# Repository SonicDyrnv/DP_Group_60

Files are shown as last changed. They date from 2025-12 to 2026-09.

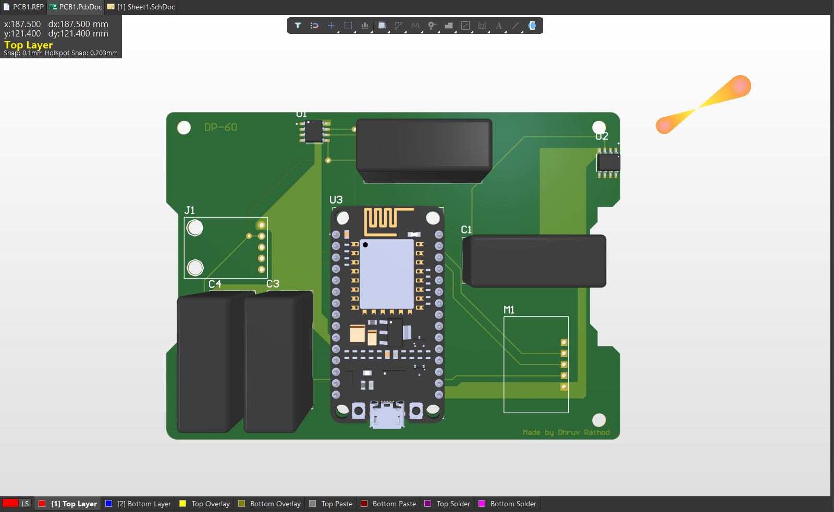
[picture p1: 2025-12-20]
Some_Overviews_In_Image/Screenshot 2025-12-20 130804.png

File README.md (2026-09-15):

# Streetlight Fault Detection & Ambulance Alerting System

An off-grid IoT system designed to monitor streetlight operations, detect physical and electrical failures in real time, and establish emergency acoustic corridors for ambulances using hybrid LoRa and ESP-NOW protocols.

---

## Overview

Traditional streetlight monitoring relies on internet connectivity or expensive cellular recharges. This project provides a cost-effective alternative that works without internet dependency. It identifies power, bulb, or structural failures at the pole level and integrates an ambulance path-clearing alert system managed from a central headquarters web portal.

---

## Key Features

* **Instant Structural Detection**: Detects pole tilting or falling immediately using 3-axis motion sensors.
* **Electrical & Light Fault Analysis**: Identifies tripped circuit breakers (MCBs), light failures when current is active, and LED flickering.
* **Ambulance Priority Corridor**: Allows HQ operators to send dynamic, targeted acoustic alerts to specific nodes to clear traffic along emergency routes.
* **Hybrid Connectivity**: Uses ESP-NOW for zero-latency node-to-node communication and long-range LoRa for transmission to the central server.

* **Continuous Power Backup**: Features an integrated battery management system recharged directly via streetlight power lines.

---

## Hardware Specifications

| Component | Function | Module Role |
| --- | --- | --- |
| **ESP32 Microcontroller** | Master controller handling LoRa & ESP-NOW stacks | Head Node |
| **ESP8266 Microcontroller** | Branch controller executing local sensing and peer routing | Branch Node |
| **LoRa SX1278 (433 MHz)** | Long-range low-power radio for HQ data link | Head Node |
| **ACS712 Current Sensor** | Measures real-time current draw to detect line flow | Both Nodes |
| **MPU6050 Gyro/Accel** | Monitors pole tilt, orientation changes, and falls | Both Nodes |
| **BH1750 Lux Sensor** | Measures digital light output intensity | Both Nodes |
| **HC-SR04 Ultrasonic** | Traffic and object distance monitoring | Both Nodes |
| **TP4056 Module** | Li-ion battery charging and protection circuit | Power System |

---

## Network Architecture

```text
               +-----------------------------+
               |  Central HQ Web Controller  |
               +--------------+--------------+
                              |
                       (LoRa 433 MHz)[cite: 1]
                              |
                              v
                   +------------------+
                   |    Head Node     | (ESP32)
                   +--------+---------+
                            |
                     (ESP-NOW Protocol)
                            |
           +----------------+----------------+
           v                                 v
+--------------------+             +--------------------+
|   Branch Node 1    | <--ESP-NOW->|   Branch Node 2    | (ESP8266)
+--------------------+             +--------------------+

```

---

## Working Principle

1. **Self-Diagnostic Loop**: Every 30 seconds, nodes read sensor inputs to evaluate power, illumination, and circuit status.
2. **Priority Interrupts**: Pole fall events bypass normal timer cycles and immediately trigger critical alarm frames.
3. **Emergency Routing**: HQ dispatches target messages formatted with `HeadNode_ID` and `BranchNode_ID`. If IDs match, local buzzers activate for a software-defined time interval.
4. **Data Relay**: Branch nodes hop messages via ESP-NOW until reaching the Head Node, which transmits packet logs to HQ over LoRa.

---

## Hardware Assembly & Manufacturing

* **Printed Circuit Board (PCB)**: Layout designed with isolated sensor tracks and centralized MCU placement to prevent signal attenuation.
* **Enclosure**: Built from 4mm laser-cut acrylic with a transparent top plate allowing unrestricted light intake for the BH1750 sensor.

---

## Authors

* **Team Members**: Rathod Dhruv Shailesh, Mayank Garg, Amey Shashikant Ballal, Avanish Kumar Patel, Divya Jain, Dilip Prajapat, Parth Vadhel.

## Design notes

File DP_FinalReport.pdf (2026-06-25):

Rathod Dhruv Shailesh∗, Mayank Garg⋆, Amey Shashikant Ballal◦ , Avanish Kumar Patel•, Divya Jain▷ , Dilip Prajapat◁ , Parth Vadhel⋄ ∗, ⋆, •, ⋄School of Computing and Electrical Engineering, Indian Institute of Technology, Mandi, India
- School of Mechanical and Material Engineering, Indian Institute of Technology, Mandi, India
▷ , ◁ School of Civil and Environmental Engineering, Indian Institute of Technology, Mandi, India
Email: yourgroupemail@students.iitmandi.ac.in

Keywords:
LoRa
ESP32
Radio receiver
Ambulance alerting system

A B S T R A C T

Streetlights are a very essential part of any road. Faults in these can lead to an increase in energy consumption and cause many accidents. For the minimization of such incidents, it is essential to fix these faulty streetlights at the fastest. The system proposed here is a solution for monitoring the functioning of a street light with addition of an alarming system for ambulances. The technology used behind this is LoRa, which is a wireless communication technology used for long range communication, ES32, a microcontroller used for short range communication (ESPNOW), wireless control and data collection and interfacing with different sensors like photo, current and orientation sensors to detect the faults. It is further embedded with an alarming system for clearance of traffic for ambulances which is done by installing an alarm and connecting with a radio receiver. Using web server programming, the data is displayed on a web page. This project was developed to produce a prototype product of a web-based streetlight fault detecting system that allows the user to detect the faulty street light. The enhancement from the existing systems is that this prototype system allowed the data to be monitored without the use of the internet and created a system for the alert for the clearance of the route for ambulances. This project involves two parts: hardware and software.

1 These authors contributed to the work equally.

## STREET LIGHT FAULT DETECTION

Streetlight Fault Detection

### 1. Introduction

Streetlight systems play an important role in ensuring public safety, energy efficiency, and comfort in urban environments. However, faults in streetlights often increase maintenance costs, lead to energy wastage, and cause illumination problems. This paper presents a streetlight fault detection and alerting system that utilizes current sensors, photosensors, ESP32 microcontrollers, and LoRa communication protocols for real-time fault reporting. The system also integrates an orientation sensor to detect the fallen streetlight poles, which is particularly useful in mountainous regions with sharp curves where continuous illumination is critical for public safety.
Beyond streetlight monitoring, this work also addresses the critical issue of ambulance delays due to traffic. The proposed design employs radio receivers integrated into selected streetlights, which are connected to an alarm system. We will have a website in our headquarters from which we will be able to monitor alarms of each streetlight with the help of LoRa Communications and ESPNOW communications. This mechanism assists in creating an emergency corridor, thereby reducing response times and improving emergency services.
The proposed solution is cost-effective, making it suitable for enhancing streetlight maintenance and energy management in urban environments.

1.Related works

Countries have millions of streetlights. It is important to detect faults in it, as it is put in work for the purpose of providing lighting in surroundings, so if they are not in working condition, they are not serving their basic purpose. Though there are various existing and proposed solutions based on IOTs, wifi based communications, GSM based communications, LoRa communications; many of them face high power consumptions, short ranges, monthly recharges and short period maintenance. Also, because we are implanting microcontrollers in most of those cases, there are large amounts of those that are underutilized, so there will also be a scope of future research on its utilizations.
- In [1] the authors used some sensors like light sensor, photo sensor, Ultrasonic sensor and LDR to detect the fault in the street light and give information about this to the center using GPS technology.
- In [2], [3] the authors used LoRaWAN (Long Range Wide Area Network) to develop a smart solution for detecting faults and automating the response over long distances with very low power consumption. Unlike in GSM and GPS systems, LoRa does not require any recharge with a working range of more than 10-15 km.
- In [4] authors suggest the idea to integrate LoRaWAN and ESPNOW communication technologies. They both work with limited energy but perform critical communication functions effectively. ESP-NOW enables short-range communication between ESP devices, whereas LoRAWAN provides longdistance transmission, The combination of these two technologies offers a cost effective and efficient solution for communication.
- In [5],[6] and [7], the authors propose a system that combines motion sensors and LDR (Light Dependent Resistor) sensors to control street lighting based on nearby movement and ambient light conditions. They also recommend an odd/even lighting scheme, where alternate lights are switched on, further optimizing energy consumption. This method helps to improve system efficiency, reduces energy usage and introduces the concept of an IoT-based dashboard for remote monitoring and management of street lights.
- In [8], 2 Author implemented system that uses traffic flow information worked on doppler effect to detect it and that system was implemented in Luyang Avenue, Lucheng City, Shanxi Province, China in May 2019, which reduced electricity consumption in that region by ∼18%.
- [9], [10], there is research on daily motionless activities of a human using Gyroscope, Accelerometer and magnetometer. The Gyroscope measures how fast an object rotates around the X, Y, Z axis. Accelerometer measures linear acceleration in the X, Y, Z axis. Magnetometer measures the direction of Earth’s magnetic field. Since these sensors detect change in orientation of the street light pole (eg. Check if the pole has fallen) and poles fall mostly in hilly areas and very few fall in urban areas so that sensor can be made attachable so that it can be deployed where it is required.
- In [11] the author proposed a smart ambulance system that computes an emergency route via Google maps APIs, the system then shares information with mobile users. The main base of this work was to inform all the other drivers on the same route as the ambulance, instead of depending on the vehicleto-vehicle or traffic management system. The author noted that if drivers do not keep his mobile app open then he would miss notification. Then the authors also suggested that future alerting systems should not rely completely on phone usage. This suggestion is important for our work, as it motivates us to use the microcontroller of our street light fault detection system for serving the purpose.
- In [12] the authors proposed an idea to solve the ambulance problem statement using the Zigbee module and when it came near the receiver then an alarm system turned ON to give information about the ambulance and it will work with the algorithm of master slave and master control.
2. Existing Products
- iSSL by ITHENA, INDIA
- Functionality: It uses NB-IOT based real-time fault alerts to improve energy efficiency, reduce maintenance costs and enhance overall light management. It includes adaptive brightness based on vehicular or human presence, and an automated schedule for turning the light on and off.
- Limitations: requires regular recharging, individual lamp monitoring is required, poor NB-IOT coverage in rural areas.
- Similarity with our solution: LoRa/LoRaWAN for long-range low-power communication, adaptive brightness system
- CityTouch Connect Cabinet Controller by Philips Signify
- Functionality: It monitors a group of streetlights. It measures voltage, current, power factor and energy consumption and detects the unauthorized opening of cabinet door. Uses web-based dashboard for real-time status and cellular network (like 2G, 3G and 4G).
- Limitations: it cannot identify the exact location of a fault within a group of streetlights, poor network availability in rural areas and the recurring cost of cellular network.
- Similarity with our solution: real-time status with the help of web-based dashboard, voltage and current monitoring
- CityLight by Motwane, India (Nashik, Maharashtra)
- Functionality: An integrated product that combines the streetlight with the dimmer. IoT-based automated, real-time monitoring and control of individual streetlights. Uses HPSV lights and adaptive brightness system to save power.
- Limitations: requires replacement of existing streetlights, it is dependent on continuous network connectivity, requires higher gateway cost.
- Similarity with our solution: adaptive brightness system, individual monitoring of lights, LoRa gateway to monitor/control light groups
- Waspmote Plug & Sense by Libelium (Spain)
- Functionality: This device can integrate multiple sensors, allowing it to be used for various tasks, one of which is smart streetlighting. It is a long range, low-power and retrofit-friendly device. It supports multiple communication protocols (LoRaWAN, Wi-Fi, Sigfox).
- Limitations: cannot identify fault at pole-level.
- Similarity with our product: Fault detection, adaptive brightness based on motion detection and scheduling of switching of light

- sylCloud by SYL Technologies sylCloud
- Functionality: It is a LoRa-based smart streetlight system. It uses map-based UI, dynamic dimming, and current/voltage monitoring. It can 6 detect overheating, voltage/current supply issues, power supply failures,
- Limitations: it requires continuous power and dense LoRa gateway placement in cities.
- Similarity with our solution: uses LoRa for communication, assigns a unique ID to each device for easy identification, and supports current, voltage, and light monitoring for fault detection
- CCMS by TRUEiSENSE (OCTIOT, India)
- Functionality: It is an IoT-based central control and monitoring system. It works on adaptive brightness based on motion detection, an automated alert system and control over individual streetlights.
- Limitations: it is dependent on network connectivity
- Similarity with our solution: Automated alerts and control over individual streetlights
- Smart Street Light Monitoring & Control by Neona Embedded Labz (India)
- Functionality: Cloud-based IoT system for managing and controlling groups of streetlights using company’s Data Connector Unit (DCU). The system uses scheduling to automatically turn lights on and off. It can store data for 45-60 days in case of network failure.
- Limitations: Scales well for highways, is dependent on network connectivity, does not provide real time information during network failures and involves higher maintenance complexity.
- Similarity with our solution: Streetlight fault Analysis
- inteliLIGHT by Flashnet / LORIOT (Europe) – Hafnarfjörður, Iceland
- Functionality: The product is based on adaptive LoRaWAN controllers with Central Management System (CMS), enabling real-time alerts. inteliLIGHT FRCM cabinet controllers and Zhaga-based controllers are used in it.
- Limitations: group-level control rather than per-lamp sensor granularity, requires reliable LoRaWAN coverage, and involves higher cost
- Similarity with our solution: it uses an AC–DC converter and operates in always-On Operation • SmartSky / Smartlight (LoRaWAN) by LOT
- EC (Turkey)
- Functionality: This system uses Light Control Unit (LCUs) are installed on each streetlight and communicate with the help of LoRaWAN controllers and DALI2(for sending data to MCU), it features a map-based interface for control, inbuilt GPS and App/web access.
- Limitations: Dependent on network connectivity and involves high costs
- Similarity with our solution: includes sensors, automated dimming, on/off scheduling of lights, and web-based monitoring
- ALC-P1 by Atreyo
- Functionality: This system uses long-range, radio-frequency-based devices (LoRa, etc.) for transmission of signals. It works on adaptive brightness system with automated on/off of streetlights and measures voltage, current and power. It supports Over the Air (OTA) for updating the fault detection logic.
- Limitations: We cannot get the pole level problem by this model
- Similarity with our solution: LoRa-based communication, adaptive brightness and current and voltage measurement

3.System Overview

The system is developed for the purpose of monitoring the streetlights and proving information regarding any fault in it. It is both hardware and software-based product.
- Objectives:
1. Identify tripping or falling of the Miniature Circuit Breaker (MCB) and generate an alert when the circuit is not completed
2. Detect tilting or falling of street light pole and generating an alert for maintenance or safety action
3. Detect the condition where current is flowing through the circuit but the LED is off
4. Detect abnormal flickering of street lights
5. Ambulance alerting system that communicate to assist emergency vehicle movements
6. Automatically dim/off street light when no motion is detected
- Advantages:
1. Real time fault detection for fast maintenance or safety action
2. Fast movement of emergency vehicles
3. No internet connection or wi-fi is required for communication
4. Continuous monitoring and fault detection in streetlight with their accurate location
5. No sim card is required, hence prevents the recharge cost
6. Much cheaper and more accurate compared to other models
7. Works even during the power cut with the help of battery
8. Charges the battery with the current in streetlight, hence the is no need to change battery

4.Hardware Used

1) ESP8266 Micro controller: Each branch node uses the ESP8266 microcontroller[14], which communicates with the ESP32 head node through ESP-NOW protocol or with other branch node through ESP-NOW protocol according to its positions. This low-latency, thus peers-topeers communication will reduce cost of external communication devices providing a local communication network. The ESP8266 collects sensor data, processes it and does as instructed. The main benefit of this is it has 11-usable GPIO pins which is enough for this system.
2) ESP32 Microcontroller: Each head node uses the ESP32 microcontroller[13], which communicates with the headquarters with the help of LoRa communications(head node). ESP32 has 30-usable GPIO pins allowing us to connect all sensors and Lora module. With its dual-core processor, integrated Wi-Fi, it is a good option since we require more pins.
3) ACS712 Current Sensor: The ACS712 5A Hall-effect current sensor[15] measures the real-time current consumption of connected loads or devices. Its high accuracy and galvanic isolation make it a good option for low-voltage IoT systems. In this system its high sensitivity is very useful.
4) MPU6050 Accelerometer and Gyroscope: The MPU6050 sensor[16] combines a 3-axis accelerometer and a 3-axis gyroscope to measure motion, tilt, and orientation. Data from this sensor allow the system to detect instant movements, enabling predictive maintenance or motion-based control applications. The sensor communicates with the microcontroller via I²C interface for efficient data transfer, which is useful for pole falling detection in this system.
5) BH1750 Light Intensity Sensor: The BH1750 sensor[17,18] is a digital light sensor that helps in detecting the amount of light intensity falling on the sensor in lux units. This sensor is useful in detecting the state of light (ON/OFF).

6) TP4056 Battery Backup System: The TP4056 module[21] is employed for charging and managing the lithium ion batteries used in the system. It provides overcharge, overdischarge, and short-circuit protection, ensuring safe and reliable operation of the power supply. The module takes care of battery charging, so there is no need of changing batteries.
7) 5V Relay Module: A 5V relay module[22] connected to the branch nodes to switch electrical loads based on sensor inputs or commands from the head node. The relay offers galvanic isolation between the low-voltage control circuitry and the high-voltage load. This device allows the microcontroller to do switching in circuits.
8) 220V AC Electronic Dimmer (E-Dimmer): The 220V ACE-Dimmer[23] allows to control the brightness of LEDs based on instructions received from the microcontroller. This helps reduce power consumption of street lights, especially in remote areas.
9) LoRa SX1278 433 MHz Transceiver Module: The LoRa SX1278 transceiver[19], operating at 433 MHz, facilitates long-range, low-power wireless communication between the head node and headquarters. Its low energy consumption and extended range make it ideal for distributed IoT networks that demand robust and scalable connectivity.
10) HC-SR04 Ultrasonic Sensor: The HC-SR04 sensor[20] is used for distance measurement, allowing us to measure change in distance for detecting motion and also distance itself, for measuring stable objects.

5.Design Overview
The proposed system uses ESP32 microcontroller in the headnode module, which contains Lora Communication module allowing it to communicate with farther devices and also supports ESP-NOW protocol allowing low-latency communications with branch nodes. Displayed Fig. 3 is the block diagram of the proposed system. A number of sensors are integrated by the branch nodes to monitor different physical properties. While the MPU6050 offers accelerometer and gyroscope data for motion and orientation detection, the ACS712 5A current sensor detects electrical current for the monitoring of electricity. The BH1750 sensor measures ambient light intensity, while the HC-SR04 ultrasonic sensor helps in measuring human traffic. A buzzer for alerts, a 5V relay module for electrical load switching or a servo motor for mechanical control and an electronic dimmer (E-Dimmer) for changeable brightness control are some of the devices used in actuation.
Two systems have been designed for different purposes
i. Head nodes
ii. Branch nodes

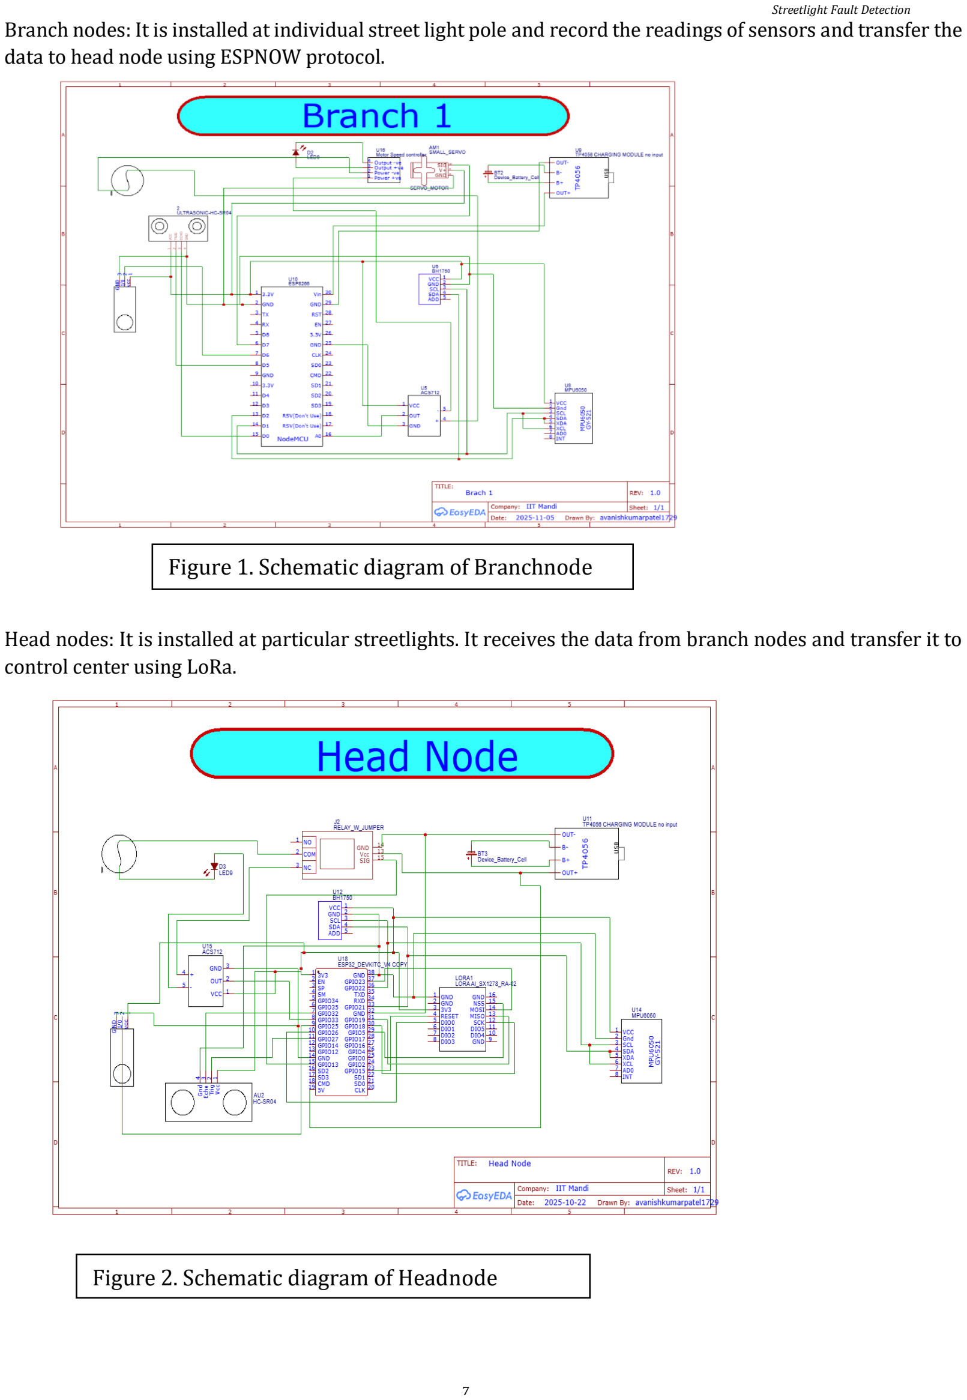
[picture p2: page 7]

Branch nodes: It is installed at individual street light pole and record the readings of sensors and transfer the data to head node using ESPNOW protocol.

Head nodes: It is installed at particular streetlights. It receives the data from branch nodes and transfer it to control center using LoRa.

Figure 1. Schematic diagram of Branchnode

Figure 2. Schematic diagram of Headnode

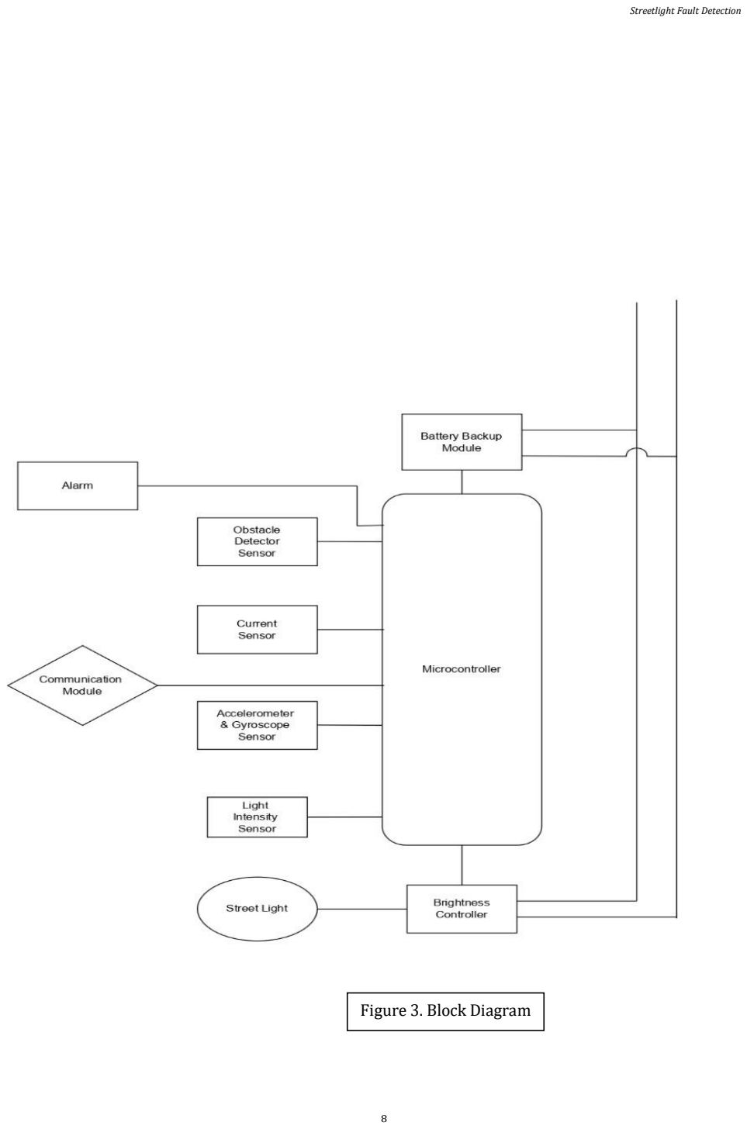
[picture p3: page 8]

Figure 3. Block Diagram

6.Working Principle

First branch node will start detecting and calibrating sensors, it will take readings of MPU6050 sensor, current sensor calibration, and detect weather all sensors including BH1750 is connected or not, if any of these is not connected it will generate fault message with all faults mentioned, the code has been written in a way such that it generates all such fault messages(some of faults are mentioned ahead) at duration of 30 seconds, till then it will just keep recording all readings and noticing all faults. The fault of fallen pole will be detected by change in readings of MPU6050, since it should be detected instantaneously as if the pole falls it can damage the system, so system should not wait for 30s if fault is of pole fallen, it should instantly generate message in this case, which is a feature of the code. Now it will detect if for some reason MCB has fallen and current is not going to LED light, then current sensor will not get detected by current sensor. Now if current is flowing but light has not turned on then in that case a photosensor will detect fault and generate a message but current sensor won’t since current is flowing. the feature of detection of flickering of LED light with the help of a photosensor has been added, through applying logic of continuous high and low readings of photosensor. Also in the case where current sensor is not detecting current and generating false faults messages, it has also been taken care in the code. All the system will be backed up by battery in case of power failure, till then it will work on adapter + cable power. The functionality mentioned above will be for both: Branchnode and Headnode. In case of Headnode(Fig. 5), the extra functionality of LoRa communication will be there, every branchnode will send fault message to Headnode by the help of espnow, and then later on Headnode will tranfer all these received fault messages to headquarter with the help of LoRa module installed in it, also it will have its own fault detecting system for own pole too. Now for clearing traffic for Ambulance, a mesh of network has been developed in which each head node has its own head node Id, if that head node id matches with the head node id transmitted then that head node will know that this alert message is either for its own or for its branchnodes. Now for reaching a particular targeted node, all head nodes will also have another id for particularly targeting it which will be in the same order with other branch nodes, those branch nodes will have its own branch node Ids only. Now whenever we transmit message of ALERT, first all head node will check if message Id of headnode in transmitted matches with its id or not, if it matches it will check if its branchnode id matches or not, if it doesn’t matches then it will transmit message to the 1st branchnode of that branch, that will check if id matches, if it will then ALERT message will successfully received by targeted node and buzzer will go on, if it doesn’t then it will transmit the same message to next node with the help of espnow, and this thing will continue until message die out, message will die out when it will reach to correct node. A feature of all node messaging is also developed, which will send a message alert to all nodes of a particular
headnode(including headnode since it will also have its own id+system). A feature of dynamic timing for buzzer being on has been added by which we will be able transmit the amount of time for buzzer to go on along with the message.

7.Manufacturing
1) PCB
The PCB of this system was designed considering the electrical requirements of all the electrical components. Schematic diagram was designed with correct pin mapping for all the electrical components. Adequate spacing between all the components has been given to reduce attenuation and interference. ESP has been placed centrally for easy connectivity with other components and photo sensor was placed near the enclosure to receive unrestricted light. Soldering has been done manually for prototype development. After assembly, the PCB was tested to endure the proper connectivity.

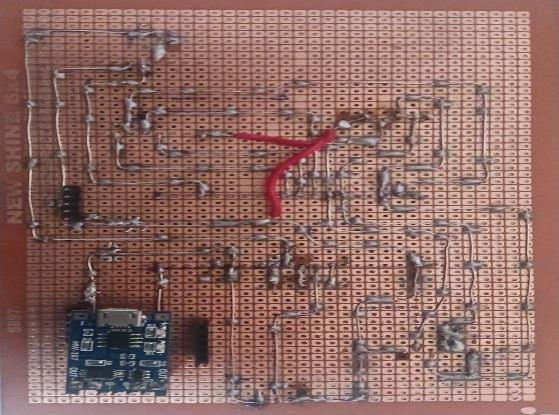
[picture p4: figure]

2) Boxing
The boxing of the streetlight fault detection unit was made up of 4 mm thick acrylic sheet as it offers good strength, electrical insulation, weather resistance and transparency for sensors that require optical exposure. This enclosure protects all the components from rai, dust and damage. The design of box was created in SolidWorks, the top face of the box is left transparent so that light fall directly over the photosensor so that it can detect the intensity of light without any resistance. The 2D profiles of each panel were exported as DXF filed and laser cutting of acrylic was done to ensure clean edges and accurate dimensions, these panels were then joint by L-brackets.
Finally, the PCB was mounted inside this box and were tested for the better functioning.

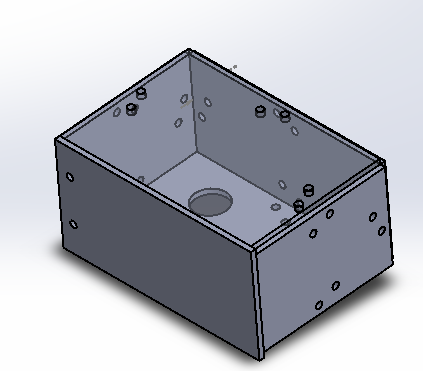
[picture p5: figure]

8.Testing

Figure 4. PCB design

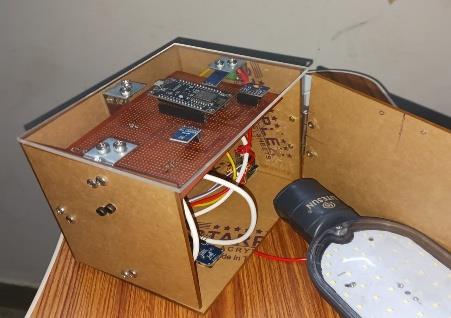
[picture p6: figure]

Figure 5. CAD design of enclosure | Figure 6. Street light fault detection system

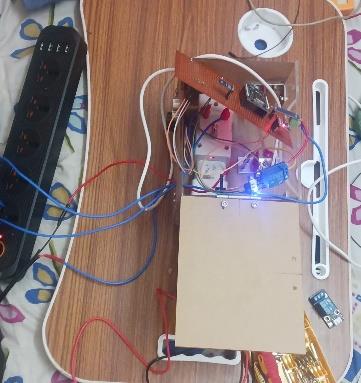
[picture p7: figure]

Figure 7. Assembling enclosure and PCB

The complete system underwent a structured testing process to ensure that it responded correctly to all fault scenarios.
1. When power supply was turned off, a “No current detected” warning was received along with the ID of that system.
2. When the system was moved, a “Pole fall detected” warning was generated along with system ID.
3. When power supply was turned on but the light was removed away from the system(condition of LED not working), “Low Light” fault was detected along with system ID.
4. When light was flickered over the system, “Flickering” fault was received along with system ID.
5. When the system received the message for ambulance, the buzzer started ringing. The operator can also manually decide the time for which buzzer has to ring.
Objectives 1, 2, 3, 4 and 5 were successfully achieved.
Objective 6 was not achieved, as the voltage was not enough to make adjustments in the intensity of light. We tried to achieve it by using servo+edimmer, relay module switchoff and ultrasonic sensor by was not able to control the intensity.

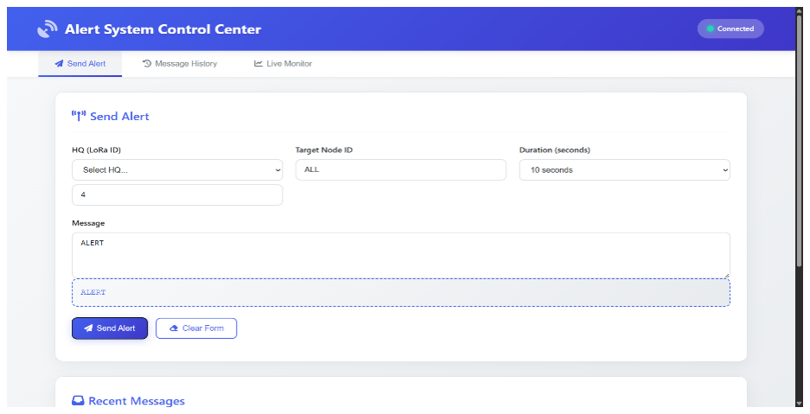
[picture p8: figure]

9.References

[1] Sathisha, K. G., Ashwinraj, Rahul, G. K., Sidharth, T., & Sneha, A. S. (2025, June). Centralized monitoring system for streetlight fault detection and location tracking. AIP Conference Proceedings, 3299(1), 050015.
[2] S. S. Saranya, C. K. P. Mani, and M. S. S. A. Tammana, “Integrat ing LoRa Technology for Smart Streetlight Systems: Enhancing Fault Detection and Adaptive Illumination,” in Proc. 2nd Int. Conf. Research Methodologies in Knowledge Management, Artificial Intelligence and Telecommunication Engineering (RMKMATE), 2025, pp. 20–25. doi: 10.1109/RMKMATE64874.2025.11042823.
[3] Bhuvaneswari, P.T.V., Parameswaran, R., Sabarna, S., Manogaran, G.I., Suriya, G., & Paventhan, A. (2020). LoRa Based Smart Street Light Management Framework. International Journal of Research in Electron ics and Computer Engineering, Vol. 6, Issue 3 (July–September 2018), ISSN: 2393-9028 (Print), ISSN: 2348-2281 (Online). Preprint available at ResearchGate.
[4] Selvaraj, V., Thamizhchelvan, A., Geca, M. J., & Natarajan, R. (2024). LoRaWAN and ESPNOW based hybrid communication system for monitoring applications. AIP Conference Proceedings, 2966(1), 020005.
[5] Aravind, S., Deepakumaran, S., Zubair, A. M., Selvam, M. E., Manish, M. P., & Venkatasamy, B. (2025). Intelligent street lighting system using RF communication. In Proceedings of the 8th International Conference on Trends in Electronics and Informatics (ICOEI) (pp. 104-109). IEEE.
[6] Hossain, A., Mostafa, S. M. G., Zilani, M. A. K., Talukder, O. I., Pranta, M. R., & Fahim, J. A. (2025). Design an Internet of Things (IoT) system for monitoring, fault detection, and controller development in street lighting. In 2025 International Conference on Electrical, Computer and Communication Engineering (ECCE). IEEE.
[7] Nanduri, A. K., Kotamraju, S. K., Sravanthi, G. L., Babu, S. R., & Kumar, K. V. K. V. L. P. (2020). IoT based automatic damaged street light fault detection management system. International Journal of Advanced Computer Science and Applications, 11(8), 412–415.

Figure 8. Manual Alert Control

[8] P. P. Ko, S. Y. Mon, and K. T. Mon, “Design and Construction of Smart Street Light System by Using Arduino and IR Sensor,” Kyaukse University Research Journal, vol. 3, pp. 143–150, 2024.
[9] Pires, I. M., Garcia, N. M., Zdravevski, E., & Lameski, P. (2022). Daily motionless activities: A dataset with accelerometer, magnetometer, gyroscope, environment, and GPS data. Scientific Data, 9, 105.
[10] Ciganda Brasca, L. M., Bernardi, P., Sonza Reorda, M., Barbieri, D., Bonaria, L., Losco, R., Marcigot, L., & Straiotto, M. (2011). A parallel tester architecture for accelerometer and gyroscope MEMS calibration and test. Journal of Electronic Testing, 27, 389–402.
[11] AbdelGhani Karkar,“Smart ambulance system for highlighting emergency-routes,” in Proc. 5th World Symposium on Web Applications and Networking (WS4), Marrakech, Morocco, 2019, pp. 1–7.
[12] Mr. G. Ramesh, Dr. V. Muneeswaran, Mr. P. Manikandan, Dr. T. Arun Prasath, “Detached range based Ambulance Alerting System,” in Proc. 2021 Int. Conf. on Advance Computing and Innovative Technologies in Engineering (ICACITE), IEEE, Gr. Noida, India, 2021, pp. 1–5, doi: 10.1109/ICACITE51222.2021.9404744.
[13] Espressif Systems, “ESP32 Series Datasheet v4.9”, Datasheet, Espressif Systems, Shanghai, China, Nov.2023.
[14] Espressif Systems, “ESP8266EX Datasheet”, Datasheet, Espressif Systems, Shanghai, China, Jul.2015.
[15] Allegro MicroSystems, “ACS712– Fully Integrated, Hall Effect-Based Linear Current Sensor”, Datasheet Rev. 7, Allegro MicroSystems, Worcester MA, USA, Sept. 2013.
[16] InvenSense Inc., “MPU-6000/MPU-6050 Motion Tracking Sensor”, Datasheet, InvenSense, San Jose CA, USA, 2013.
[17] NXP Semiconductors, “BH1750FVI Digital Light Sensor”, Datasheet, NXP, Eindhoven, The Netherlands, Apr. 2016.
[18] Sunrom Electronics, “Digital Light Sensor– BH1750FVI Module”, Module Spec, Sunrom Electronics, Chennai, India, 2024.
[19] Semtech Corporation, “SX1276/77/78/79 LoRa™ Long Range Transceiver”, Datasheet, Semtech Corporation, Camarillo CA, USA, 2017.
[20] ELECFREAKS, “HC-SR04 Ultrasonic Ranging Module,” Datasheet, Shenzhen, China, 2013.
[21] NanJing Top Power ASIC Corp., “TP4056– 1A Standalone Linear Li Ion Battery Charger,” Datasheet, Rev. 1.0, 2017.
[22] Songle Relay Co. Ltd., “SRD-05VDC-SL-C Relay Module,” Datasheet, Zhejiang, China, 2015.
[23] RobotDyn, “AC Light Dimmer Module for Arduino,” Module Specification, 2018

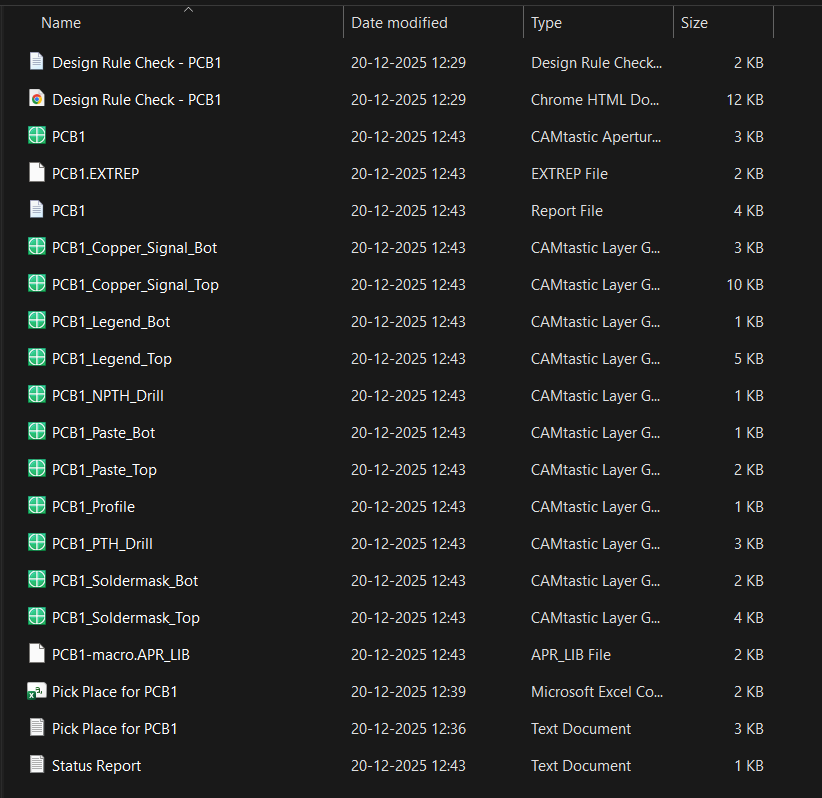
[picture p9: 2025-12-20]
Some_Overviews_In_Image/Screenshot 2025-12-20 130325.png

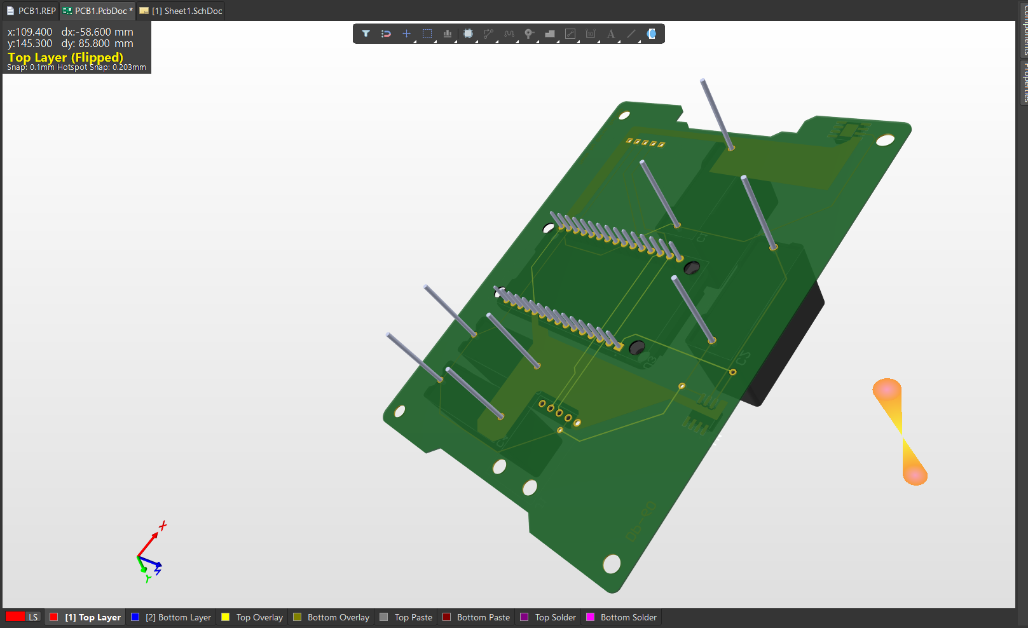
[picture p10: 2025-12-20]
Some_Overviews_In_Image/Screenshot 2025-12-20 130921.png

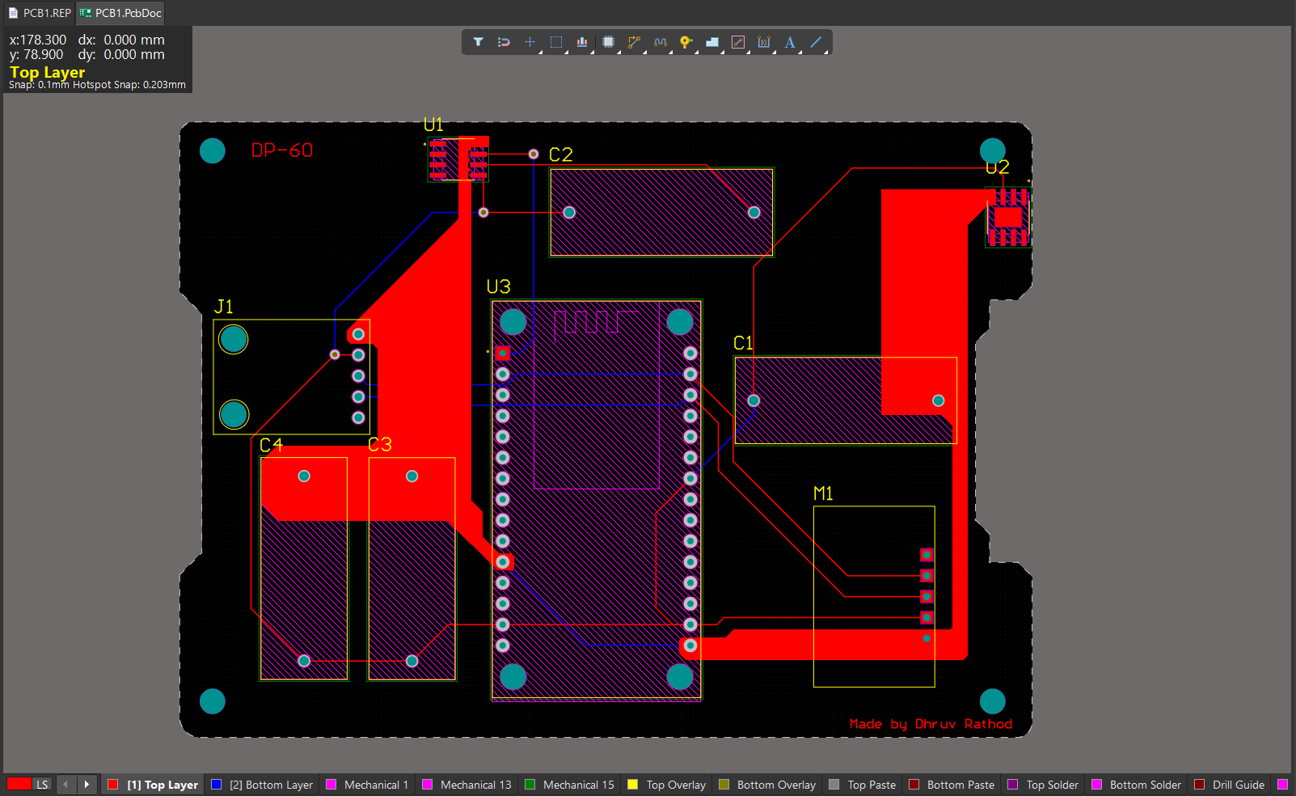
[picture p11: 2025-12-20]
Some_Overviews_In_Image/Screenshot 2025-12-20 130148.png

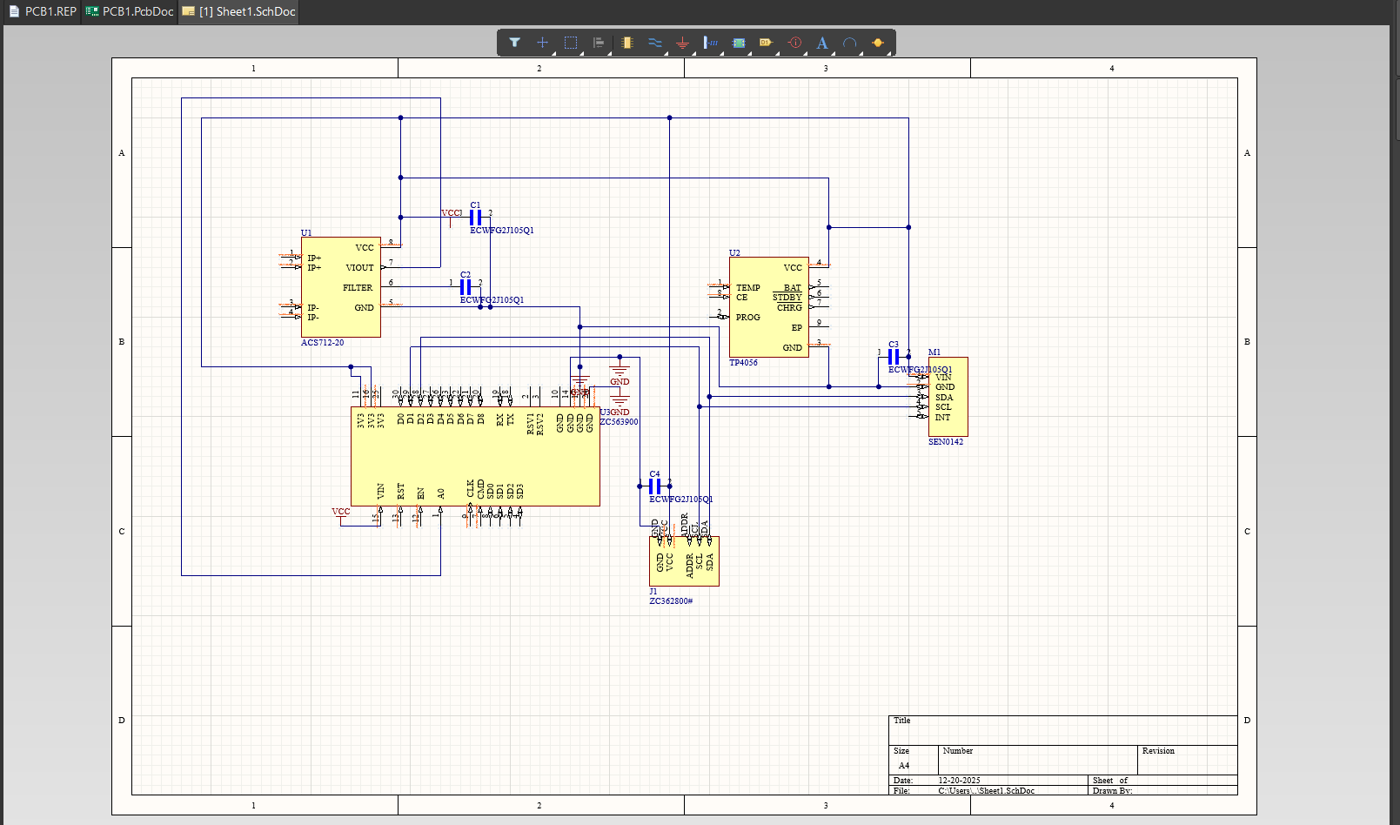
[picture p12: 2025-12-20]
Some_Overviews_In_Image/Screenshot 2025-12-20 130218.png

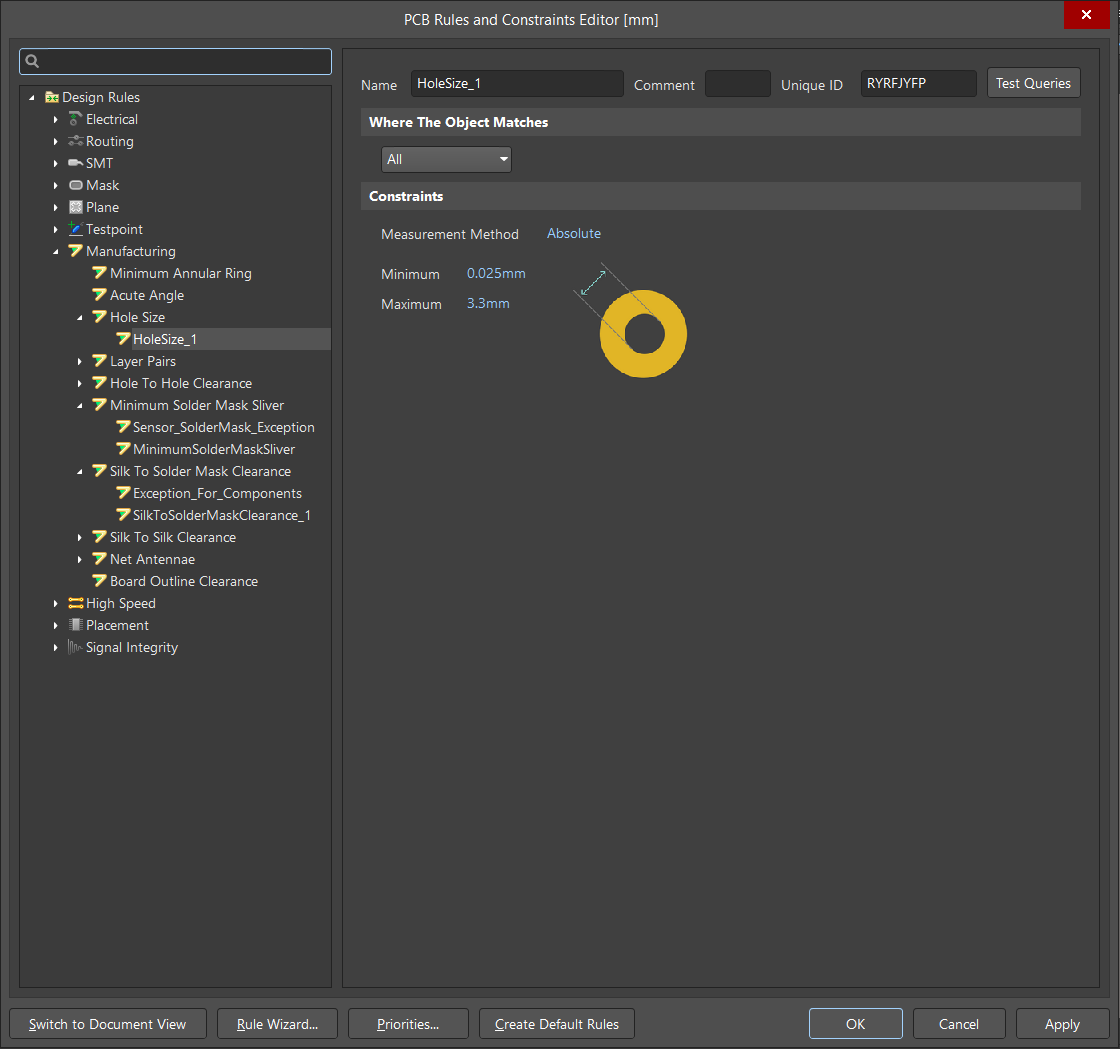
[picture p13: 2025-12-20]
Some_Overviews_In_Image/Screenshot 2025-12-20 130255.png

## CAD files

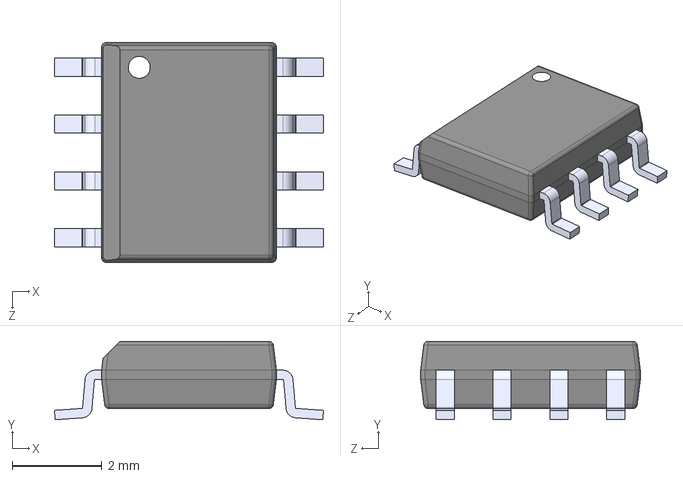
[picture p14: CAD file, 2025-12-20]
Comp_DP_60/ACS712-20.STEP
6.00 x 1.75 x 4.90 mm

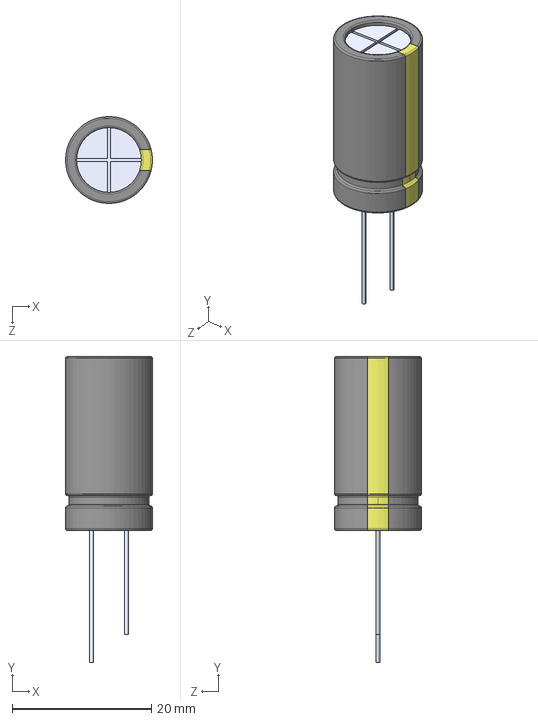
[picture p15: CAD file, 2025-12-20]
Comp_DP_60/478CKS010M--3DModel-STEP-1.STEP
12.5 x 44.0 x 12.5 mm

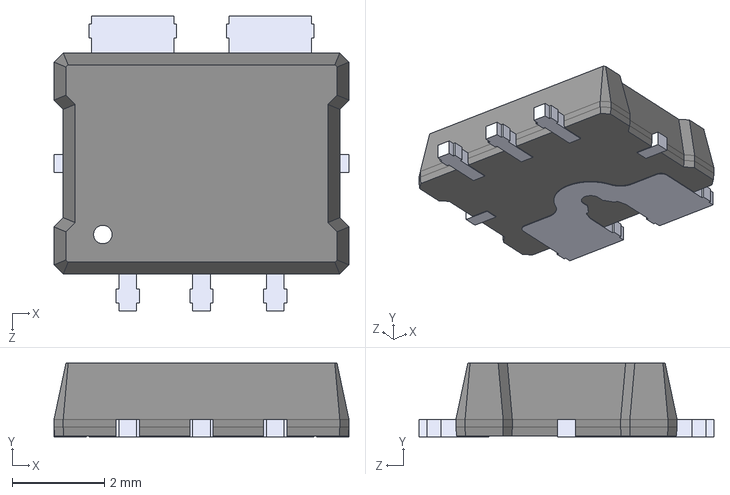
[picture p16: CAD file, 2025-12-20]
Comp_DP_60/ACS780LLRTR-100B-T.STEP
6.40 x 1.60 x 6.40 mm

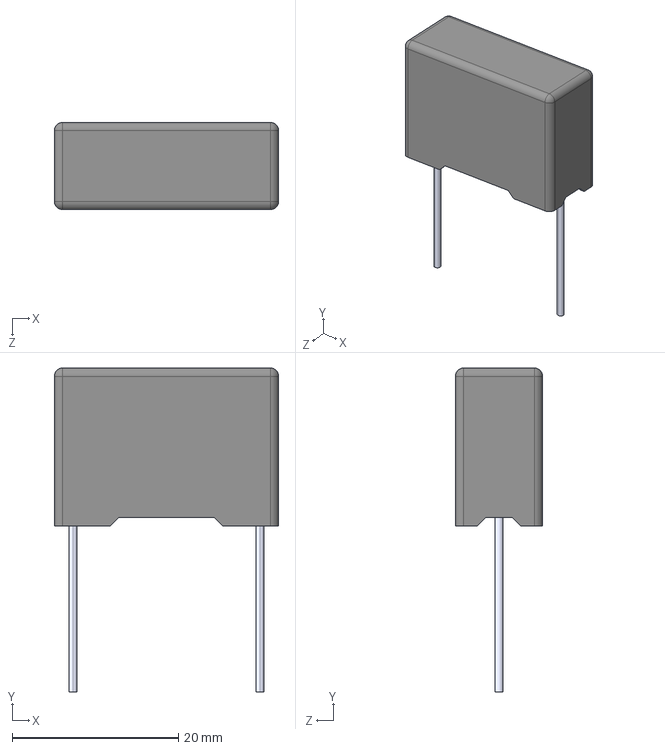
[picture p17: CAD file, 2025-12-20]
Comp_DP_60/ECWFG2J105Q1.STEP
27.0 x 39.0 x 10.5 mm

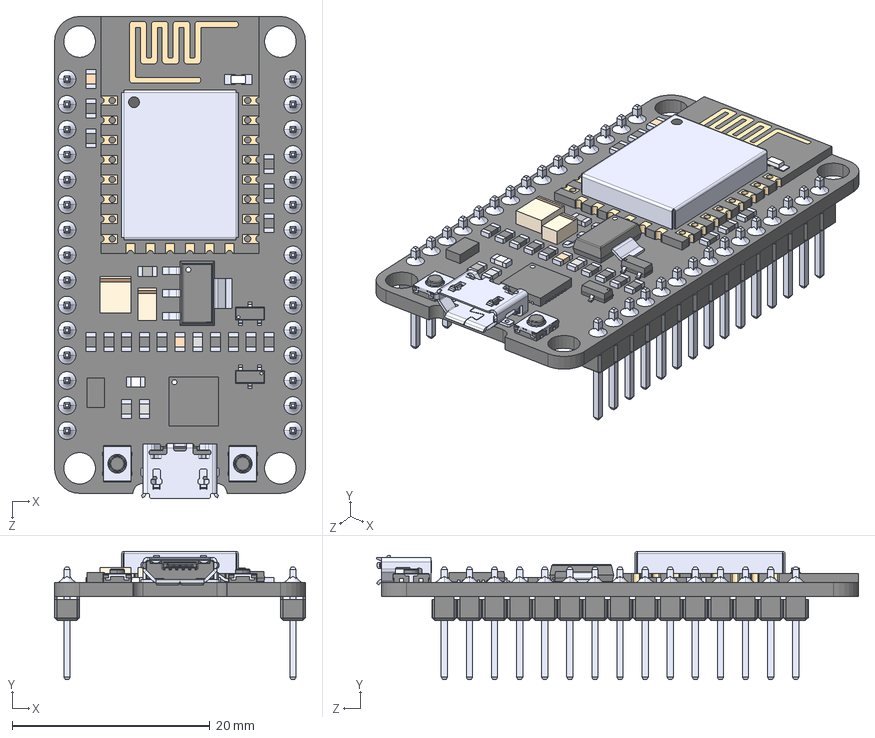
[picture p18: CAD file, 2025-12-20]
Comp_DP_60/ZC563900--3DModel-STEP-269445.STEP
25.4 x 13.0 x 48.8 mm

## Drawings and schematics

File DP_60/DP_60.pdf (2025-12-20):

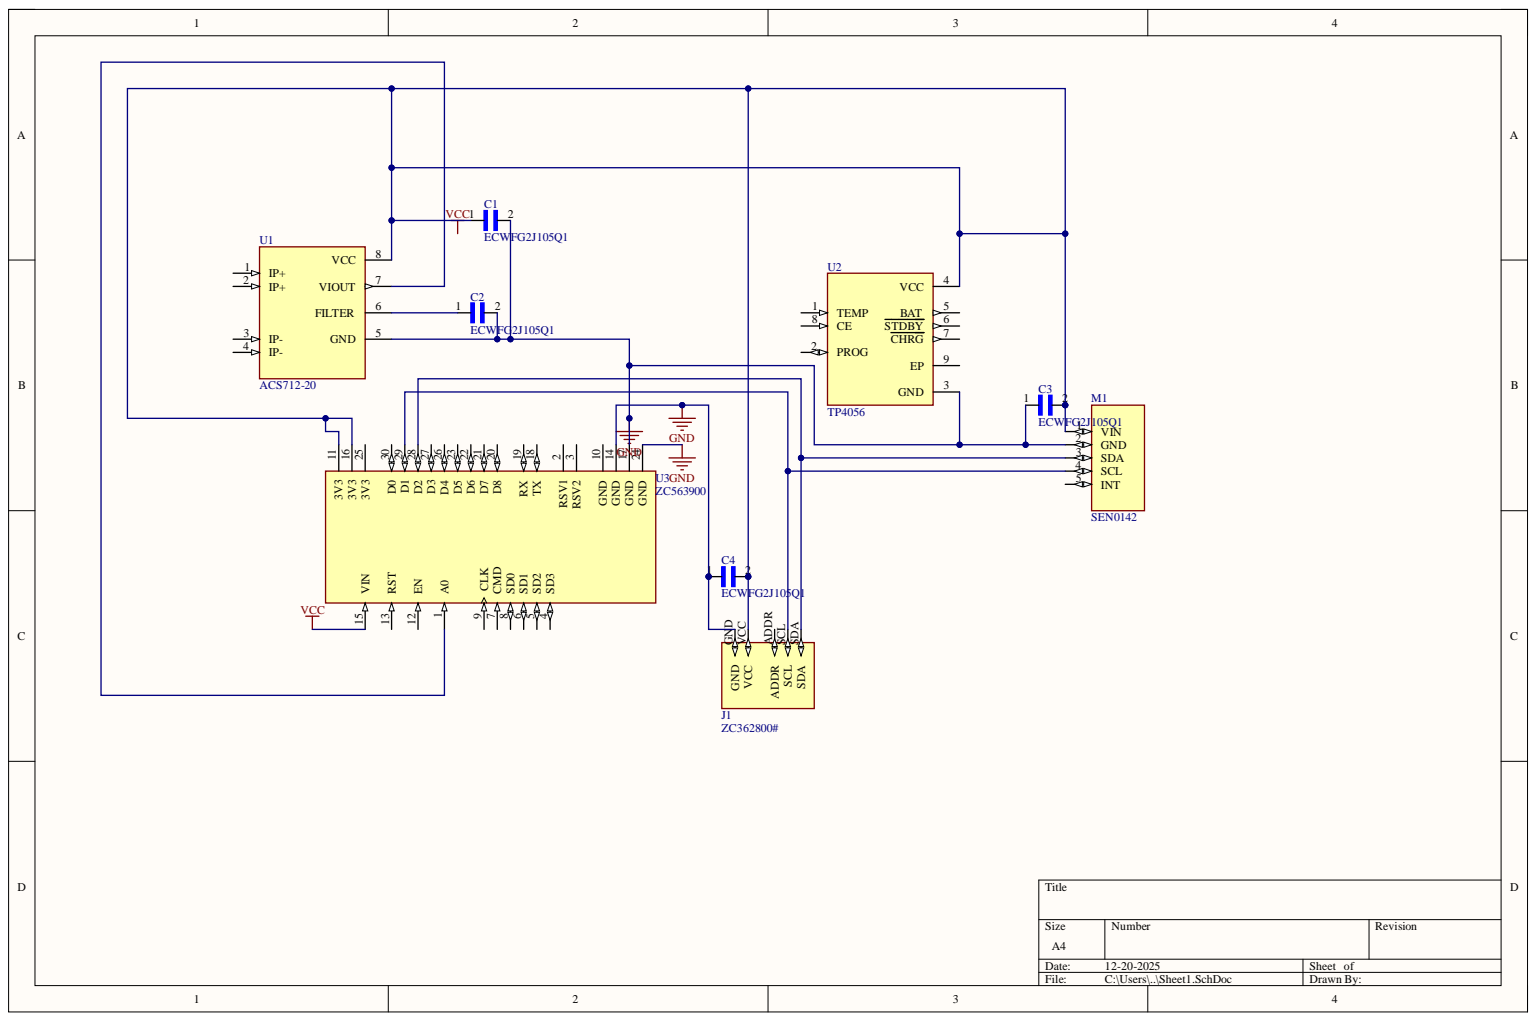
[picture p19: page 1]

SDA SDA SCL SCL ADDR ADDR

VCC VCC GND GND J1

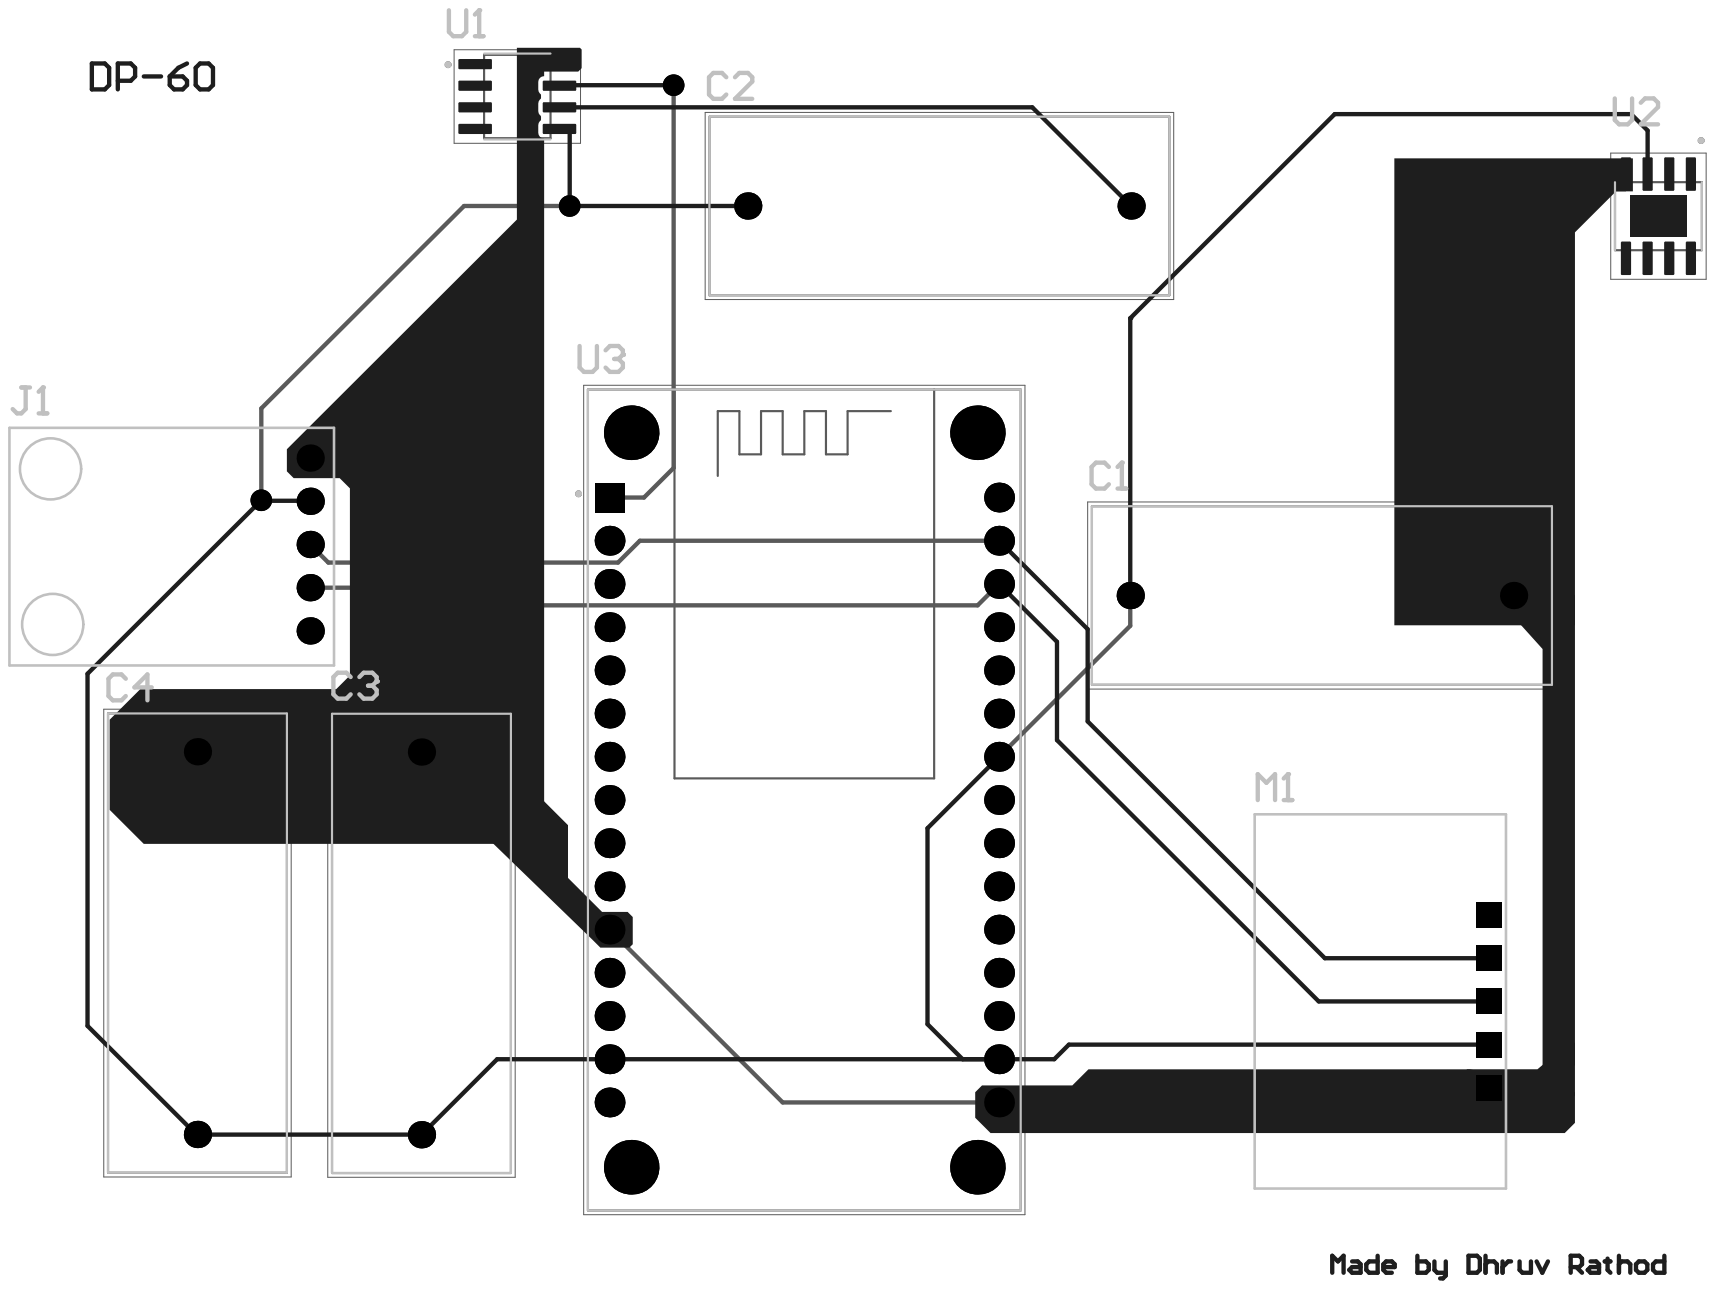
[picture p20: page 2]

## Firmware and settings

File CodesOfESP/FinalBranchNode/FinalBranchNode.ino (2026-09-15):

#include <ESP8266WiFi.h>
#include <espnow.h>
#include <Wire.h>
#include <BH1750.h>
#include <MPU6050.h>
#include <math.h>

// ---------------- CONFIG ----------------
#define NODE_ID "4001"     // change this for each branch node
#define BUZZER_PIN 12      // D6
#define ACS_PIN A0
#define LED_PIN 0          // D3
#define WIFI_CHANNEL 1

// ---------------- ESP-NOW PEERS ----------------
uint8_t prevNode[] = {0xF8,0xB3,0xB7,0x87,0x33,0xAA};  // Previous node MAC
uint8_t nextNode[] = {0x6C,0xC8,0x40,0x4F,0x69,0x94};  // Next node MAC

// ---------------- OBJECTS ----------------
BH1750 lightMeter;
MPU6050 mpu;

// ---------------- FLAGS ----------------
bool bh1750_ok = false;
bool mpu_ok = false;


// ---------------- THRESHOLDS / PARAMETERS ----------------
const float LUX_THRESHOLD = 300.0;
const unsigned long READ_INTERVAL = 1000;
const float TILT_THRESHOLD = 45.0;
const float CURRENT_THRESHOLD = 0.035;
const float alpha = 0.2;
const int SAMPLE_COUNT = 10;

// Pole fallen detection parameters - BALANCED SENSITIVITY
const float SPEED_CHANGE_THRESHOLD = 0.8;  // Sensitive but not too sensitive
const float ANGLE_CHANGE_THRESHOLD = 10.0; // Sensitive but not too sensitive
const unsigned long POLE_FALL_COOLDOWN = 30000;
const unsigned long POLE_FALL_CHECK_INTERVAL = 50; // Check every 50ms

// NEW: Direction-specific acceleration thresholds
const float X_ACCEL_THRESHOLD = 1.5;  // Threshold for X-axis acceleration (g)
const float Y_ACCEL_THRESHOLD = 1.5;  // Threshold for Y-axis acceleration (g)
const float Z_ACCEL_THRESHOLD = 2.0;  // Threshold for Z-axis acceleration (g)
const float ACCEL_DURATION_THRESHOLD = 100; // Minimum duration (ms) for acceleration to be considered

// Noise filtering
const float NOISE_THRESHOLD = 0.1; // Minimum change to consider
const int STABLE_READINGS = 2; // Need 2 stable readings before processing

// ---------------- GLOBAL VARS ----------------
float sensorOffset = 0.0;
float filteredCurrent = 0.0;
bool calibrated = false;
bool poleFallen = false;
float baselineX = 0.0, baselineY = 0.0, baselineZ = 1.0;

// For tracking changes in acceleration and angle
float prevAccelX = 0.0, prevAccelY = 0.0, prevAccelZ = 0.0;
float prevAngle = 0.0;
unsigned long lastPoleFallAlert = 0;
unsigned long lastPoleFallCheck = 0;
unsigned long lastMPUCheck = 0;
const unsigned long MPU_RECHECK_INTERVAL = 5000;

// NEW: Variables for direction-specific acceleration detection
unsigned long xAccelStartTime = 0;
unsigned long yAccelStartTime = 0;
unsigned long zAccelStartTime = 0;
bool xAccelDetected = false;
bool yAccelDetected = false;
bool zAccelDetected = false;

// Noise filtering variables
float stableAx = 0.0, stableAy = 0.0, stableAz = 0.0;
int stableCount = 0;

// Current sensor specific variables
unsigned long lastRecalibration = 0;
const unsigned long RECALIBRATION_INTERVAL = 11000;

// Fault generation cooldown
static unsigned long lastFaultGeneration = 0;
const unsigned long FAULT_GENERATION_COOLDOWN = 10000;

float luxSamples[SAMPLE_COUNT];
bool lightStates[SAMPLE_COUNT];
int sampleIndex = 0;
bool bufferFilled = false;

unsigned long lastCurrentRead = 0;
unsigned long lastSend = 0;

volatile bool msgPending = false;
String pendingMsg = "";
uint8_t pendingSender[6];

// ---------------- ALERT BUZZER VARIABLES ----------------
unsigned long alertStart = 0;
bool alertActive = false;
unsigned long alertDurationMs = 0;

// ---------------- FUNCTION DECLARATIONS ----------------
void sendTo(const uint8_t *mac, const String &msg);
void forwardMsg(const String &msg, const uint8_t *exclude);
void onDataRecv(uint8_t *mac, uint8_t *incomingData, uint8_t len);
void beep(int t);
float getSensorOffset();
float getACCurrent();
void calibrateMPU();
void checkSensors();
void triggerBuzzerFor(unsigned long ms);
void processIncomingMessage(const String &msg, const uint8_t *sender);
bool isSender(const uint8_t *mac1, const uint8_t *mac2);
void printMacAddress(const uint8_t *mac);
void recalibrateCurrentSensor();
void checkPoleFallAsync();
bool initializeMPU();
void sendPoleFallFault();

// ---------------- SETUP ----------------
void setup() {
  Serial.begin(9600);
  Serial.println("=== NODE " + String(NODE_ID) + " STARTING ===");

  pinMode(BUZZER_PIN, OUTPUT);
  pinMode(LED_PIN, OUTPUT);
  digitalWrite(BUZZER_PIN, LOW);
  digitalWrite(LED_PIN, LOW);

  Wire.begin(D2, D1);
  Wire.setClock(100000);

  // Initialize MPU6050 first
  mpu_ok = initializeMPU();
  
  // Sensors
  bh1750_ok = lightMeter.begin();
  if (bh1750_ok) Serial.println("BH1750 OK");
  else Serial.println("BH1750 not detected");

  // Calibrate current sensor - wait 60s for stabilization, then average 10 readings
  Serial.println("Calibrating current sensor... This will take approximately 70 seconds.");
  sensorOffset = getSensorOffset();
  Serial.print("Initial Sensor Offset: "); Serial.println(sensorOffset);
  lastRecalibration = millis();
  
  if (mpu_ok) calibrateMPU();

  // ESP-NOW setup
  WiFi.mode(WIFI_STA);
  WiFi.disconnect();

  if (esp_now_init() != 0) {
    Serial.println("ESP-NOW init failed!");
    ESP.restart();
  }

  esp_now_set_self_role(ESP_NOW_ROLE_COMBO);
  esp_now_register_recv_cb(onDataRecv);

  // Add peers with error checking
  if (esp_now_add_peer(prevNode, ESP_NOW_ROLE_COMBO, WIFI_CHANNEL, NULL, 0) != 0) {
    Serial.println("Failed to add previous node as peer");
  } else {
    Serial.print("Added previous node as peer: ");
    printMacAddress(prevNode);
  }
  
  if (esp_now_add_peer(nextNode, ESP_NOW_ROLE_COMBO, WIFI_CHANNEL, NULL, 0) != 0) {
    Serial.println("Failed to add next node as peer");
  } else {
    Serial.print("Added next node as peer: ");
    printMacAddress(nextNode);
  }

  Serial.println("System Ready, Node: " NODE_ID);
}

// ---------------- LOOP ----------------
void loop() {
  static unsigned long lastCheck = 0;

  if (msgPending) {
    processIncomingMessage(pendingMsg, pendingSender);
    msgPending = false;
  }

  if (alertActive && (millis() - alertStart >= alertDurationMs)) {
    digitalWrite(BUZZER_PIN, LOW);
    digitalWrite(LED_PIN, LOW);
    alertActive = false;
    Serial.println("Alert completed, buzzer off.");
  }

  if (millis() - lastCheck > 3000) {
    lastCheck = millis();
    checkSensors();
  }
  
  // Asynchronous pole fall detection - check every 50ms
  if (mpu_ok && calibrated) {
    checkPoleFallAsync();
  }
  
  // Periodically check MPU connection and try to reconnect if needed
  if (millis() - lastMPUCheck > MPU_RECHECK_INTERVAL) {
    lastMPUCheck = millis();
    if (!mpu_ok) {
      Serial.println("Attempting to reconnect MPU6050...");
      mpu_ok = initializeMPU();
      if (mpu_ok) {
        calibrateMPU();
        Serial.println("MPU6050 reconnected and recalibrated");
      }
    }
  }
  
  // Periodic recalibration to prevent drift
  if (millis() - lastRecalibration > RECALIBRATION_INTERVAL) {
    recalibrateCurrentSensor();
  }
}

// ---------------- MPU INITIALIZATION ----------------
bool initializeMPU() {
  for (int attempt = 0; attempt < 3; attempt++) {
    mpu.initialize();
    delay(100);
    
    if (mpu.testConnection()) {
      Serial.println("MPU6050 OK");
      mpu.setSleepEnabled(false);
      mpu.setFullScaleGyroRange(MPU6050_GYRO_FS_250);
      mpu.setFullScaleAccelRange(MPU6050_ACCEL_FS_2);
      return true;
    }
    delay(500);
  }
  
  Serial.println("MPU6050 not detected after 3 attempts");
  return false;
}

// ---------------- ASYNCHRONOUS POLE FALL DETECTION ----------------
void checkPoleFallAsync() {
  unsigned long now = millis();
  
  if (now - lastPoleFallCheck < POLE_FALL_CHECK_INTERVAL) {
    return;
  }
  lastPoleFallCheck = now;
  
  int16_t axRaw, ayRaw, azRaw;
  
  if (!mpu.testConnection()) {
    Serial.println("MPU6050 disconnected during pole fall check");
    mpu_ok = false;
    return;
  }
  
  mpu.getAcceleration(&axRaw, &ayRaw, &azRaw);
  float ax = axRaw / 16384.0;
  float ay = ayRaw / 16384.0;
  float az = azRaw / 16384.0;
  
  // Simple noise filtering - only process if change is significant
  float changeX = fabs(ax - stableAx);
  float changeY = fabs(ay - stableAy);
  float changeZ = fabs(az - stableAz);
  
  if (changeX < NOISE_THRESHOLD && changeY < NOISE_THRESHOLD && changeZ < NOISE_THRESHOLD) {
    stableCount++;
    if (stableCount >= STABLE_READINGS) {
      // Update stable values
      stableAx = ax;
      stableAy = ay;
      stableAz = az;
    }
  } else {
    // Significant change detected, reset stable count
    stableCount = 0;
  }
  
  // Use stable values for calculations
  float processAx = (stableCount >= STABLE_READINGS) ? stableAx : ax;
  float processAy = (stableCount >= STABLE_READINGS) ? stableAy : ay;
  float processAz = (stableCount >= STABLE_READINGS) ? stableAz : az;
  
  float totalG = sqrt(processAx * processAx + processAy * processAy + processAz * processAz);
  float currentAngle = 0;
  if (totalG > 0.0001) {
    currentAngle = acos(processAz / totalG) * (180.0 / PI);
  }
  
  float accelChange = sqrt(
    pow(processAx - prevAccelX, 2) + 
    pow(processAy - prevAccelY, 2) + 
    pow(processAz - prevAccelZ, 2)
  );
  
  float angleChange = fabs(currentAngle - prevAngle);
  
  // NEW: Check for direction-specific acceleration
  bool xAccelTriggered = false;
  bool yAccelTriggered = false;
  bool zAccelTriggered = false;
  
  // X-axis acceleration check
  if (fabs(processAx) > X_ACCEL_THRESHOLD) {
    if (!xAccelDetected) {
      xAccelDetected = true;
      xAccelStartTime = now;
    } else if (now - xAccelStartTime > ACCEL_DURATION_THRESHOLD) {
      xAccelTriggered = true;
    }
  } else {
    xAccelDetected = false;
  }
  
  // Y-axis acceleration check
  if (fabs(processAy) > Y_ACCEL_THRESHOLD) {
    if (!yAccelDetected) {
      yAccelDetected = true;
      yAccelStartTime = now;
    } else if (now - yAccelStartTime > ACCEL_DURATION_THRESHOLD) {
      yAccelTriggered = true;
    }
  } else {
    yAccelDetected = false;
  }
  
  // Z-axis acceleration check
  if (fabs(processAz - 1.0) > Z_ACCEL_THRESHOLD) {  // Subtract 1.0 to account for gravity
    if (!zAccelDetected) {
      zAccelDetected = true;
      zAccelStartTime = now;
    } else if (now - zAccelStartTime > ACCEL_DURATION_THRESHOLD) {
      zAccelTriggered = true;
    }
  } else {
    zAccelDetected = false;
  }
  
  // Debug output
  static unsigned long lastDebug = 0;
  // if (now - lastDebug > 200) {
  //   lastDebug = now;
  //   Serial.print("🔍 MPU - Accel: X=");
  //   Serial.print(processAx, 3);
  //   Serial.print(", Y=");
  //   Serial.print(processAy, 3);
  //   Serial.print(", Z=");
  //   Serial.print(processAz, 3);
  //   Serial.print(", Total=");
  //   Serial.print(totalG, 3);
  //   Serial.print(", Angle=");
  //   Serial.print(currentAngle, 2);
  //   Serial.print("°, AccelChange=");
  //   Serial.print(accelChange, 3);
  //   Serial.print(", AngleChange=");
  //   Serial.println(angleChange, 2);
  // }
  
  // Update previous values
  prevAccelX = processAx;
  prevAccelY = processAy;
  prevAccelZ = processAz;
  prevAngle = currentAngle;
  
  // Check cooldown
  if (now - lastPoleFallAlert < POLE_FALL_COOLDOWN) {
    return;
  }
  
  // IMMEDIATE DETECTION - Check any of the conditions
  bool poleFallDetected = false;
  String detectionReason = "";
  
  // Condition 1: Sudden acceleration change
  if (accelChange > SPEED_CHANGE_THRESHOLD) {
    poleFallDetected = true;
    detectionReason = "Acceleration change: " + String(accelChange, 3);
  }
  
  // Condition 2: Sudden angle change
  if (angleChange > ANGLE_CHANGE_THRESHOLD) {
    poleFallDetected = true;
    detectionReason = "Angle change: " + String(angleChange, 2) + "°";
  }
  
  // NEW: Condition 3: X-axis acceleration
  if (xAccelTriggered) {
    poleFallDetected = true;
    detectionReason = "X-axis acceleration: " + String(processAx, 3) + "g";
  }
  
  // NEW: Condition 4: Y-axis acceleration
  if (yAccelTriggered) {
    poleFallDetected = true;
    detectionReason = "Y-axis acceleration: " + String(processAy, 3) + "g";
  }
  
  // NEW: Condition 5: Z-axis acceleration
  if (zAccelTriggered) {
    poleFallDetected = true;
    detectionReason = "Z-axis acceleration: " + String(fabs(processAz - 1.0), 3) + "g";
  }
  
  // IMMEDIATE ACTION ON FIRST DETECTION
  if (poleFallDetected) {
    poleFallen = true;
    lastPoleFallAlert = now;
    
    Serial.println("POLE FALL DETECTED! Reason: " + detectionReason);
    Serial.println("Sending immediate fault...");
    
    sendPoleFallFault();
    // beep(5);
    
    // Reset flags after sending
    poleFallen = false;
    xAccelDetected = false;
    yAccelDetected = false;
    zAccelDetected = false;
  }
}

// ---------------- SEND POLE FALL FAULT ----------------
void sendPoleFallFault() {
  String msg = String(NODE_ID) + " -> FAULTS: [POLE_FALL]";
  Serial.println("Sending immediate pole fall fault: " + msg);
  forwardMsg(msg, NULL);
}

// ---------------- PROCESS INCOMING ----------------
void processIncomingMessage(const String &msg, const uint8_t *sender) {
  Serial.print("Received from ");
  printMacAddress(sender);
  Serial.println(": " + msg);

  String src = "", tgt = "", dur = "", cmd = "";
  bool isAlertFormat = false;
  
  if (msg.indexOf("SRC:") >= 0) {
    isAlertFormat = true;
    int pSrc = msg.indexOf("SRC:");
    int pTgt = msg.indexOf("|TGT:");
    int pDur = msg.indexOf("|DUR:");
    int pMsg = msg.indexOf("|MSG:");

    if (pSrc >= 0 && pTgt > pSrc) src = msg.substring(pSrc + 4, pTgt);
    if (pTgt >= 0 && pDur > pTgt) tgt = msg.substring(pTgt + 5, pDur);
    if (pDur >= 0 && pMsg > pDur) dur = msg.substring(pDur + 5, pMsg);
    if (pMsg >= 0) cmd = msg.substring(pMsg + 5);

    src.trim(); tgt.trim(); dur.trim(); cmd.trim();
    
    Serial.println("Parsed: SRC=" + src + ", TGT=" + tgt + ", DUR=" + dur + ", MSG=" + cmd);
  }

  if (isAlertFormat && (tgt == NODE_ID || tgt == "ALL")) {
    Serial.println("Target matches this node ID or ALL → Activating buzzer.");
    if (cmd.equalsIgnoreCase("ALERT")) {
      unsigned long durMs = dur.toInt() * 1000UL;
      if (durMs == 0) durMs = 5000;
      triggerBuzzerFor(durMs);
    }
  }
  else if (String(NODE_ID) == "4001" && isAlertFormat && cmd.equalsIgnoreCase("ALERT")) {
    Serial.println("ALERT not for 4001 → forwarding backward to previous node.");
    Serial.print("Forwarding to previous node: ");
    printMacAddress(prevNode);
    sendTo(prevNode, msg);
  }
  else {
    Serial.println("↩ Normal message flow → forward to both directions if applicable.");
    forwardMsg(msg, sender);
  }
  
  if (isAlertFormat && tgt == "ALL") {
    Serial.println("Forwarding ALL message to ensure it reaches all nodes");
    forwardMsg(msg, sender);
  }
}

// ---------------- TRIGGER BUZZER ----------------
void triggerBuzzerFor(unsigned long ms) {
  Serial.printf("Buzzing for %.1f sec...\n", ms / 1000.0);
  digitalWrite(BUZZER_PIN, HIGH);
  digitalWrite(LED_PIN, HIGH);
  alertStart = millis();
  alertDurationMs = ms;
  alertActive = true;
}

// ---------------- SENSOR CHECK ----------------
void checkSensors() {
  unsigned long now = millis();
  String faultList = "";

  float lux = -1, tiltAngle = -1;
  String lightStatus = "N/A";

  // BH1750
  if (bh1750_ok) {
    lux = lightMeter.readLightLevel();
    if (lux >= 0 && lux < 200000) {
      luxSamples[sampleIndex] = lux;
      lightStates[sampleIndex] = (lux >= LUX_THRESHOLD);
      sampleIndex = (sampleIndex + 1) % SAMPLE_COUNT;
      if (sampleIndex == 0) bufferFilled = true;

      int validCount = bufferFilled ? SAMPLE_COUNT : sampleIndex;
      int onCount = 0, offCount = 0, stateChanges = 0;
      for (int i = 0; i < validCount; i++) {
        if (lightStates[i]) onCount++;
        else offCount++;
        if (i > 0 && lightStates[i] != lightStates[i - 1]) stateChanges++;
      }

      if (stateChanges >= 3) lightStatus = "FLICKERING";
      else if (onCount == validCount) lightStatus = "ON";
      else if (offCount == validCount) lightStatus = "OFF";
      else lightStatus = "TRANSITION";
    } else {
      faultList += "LIGHT_SENSOR_ERROR, ";
      bh1750_ok = false;
    }
  } else faultList += "LIGHT_SENSOR_NOT_CONNECTED, ";

  // MPU6050
  if (mpu_ok) {
    int16_t axRaw, ayRaw, azRaw;
    if (mpu.testConnection()) {
      mpu.getAcceleration(&axRaw, &ayRaw, &azRaw);
      float ax = axRaw / 16384.0;
      float ay = ayRaw / 16384.0;
      float az = azRaw / 16384.0;
      float totalG = sqrt(ax * ax + ay * ay + az * az);
      if (totalG > 0.0001) tiltAngle = acos(az / totalG) * (180.0 / PI);
      
      prevAccelX = ax;
      prevAccelY = ay;
      prevAccelZ = az;
      prevAngle = tiltAngle;
      
      if (!poleFallen && calibrated) {
        float dx = fabs(ax - baselineX);
        float dy = fabs(ay - baselineY);
        float dz = fabs(az - baselineZ);
        if (dx > 0.3 || dy > 0.3 || dz > 0.4 || tiltAngle > TILT_THRESHOLD)
          poleFallen = true;
      }
    } else {
      faultList += "MPU_SENSOR_ERROR, ";
      mpu_ok = false;
    }
  } else faultList += "MPU_SENSOR_NOT_CONNECTED, ";

  // ACS - Always check for NO_CURRENT fault
  bool checkCurrentFault = false;
  if (now - lastCurrentRead >= READ_INTERVAL) {
    lastCurrentRead = now;
    float current = getACCurrent();
    
    if (filteredCurrent == 0 || abs(current - filteredCurrent) > 2.0) {
      filteredCurrent = current;
    } else {
      filteredCurrent = alpha * current + (1 - alpha) * filteredCurrent;
    }
    
    if (filteredCurrent < 0) filteredCurrent = 0;
    
    // Always check for current fault
    checkCurrentFault = true;
  }

  // Faults
  if (lightStatus == "OFF") faultList += "LOW_LIGHT, ";
  if (lightStatus == "FLICKERING") faultList += "FLICKERING, ";
  if (poleFallen) {
    faultList += "TILT, ";
    poleFallen = false;
  }
  
  // Always add NO_CURRENT fault if detected
  if (checkCurrentFault && filteredCurrent < CURRENT_THRESHOLD) {
    faultList += "NO_CURRENT, ";
  }
  
  if (faultList.endsWith(", ")) faultList.remove(faultList.length() - 2);

  Serial.println("----------- SENSOR STATUS -----------");
  Serial.print("Lux: "); Serial.println(lux);
  Serial.print("Tilt: "); Serial.println(tiltAngle);
  Serial.print("Current: "); Serial.print(filteredCurrent, 3); Serial.println("A");
  Serial.print("Raw Current: "); Serial.print(getACCurrent(), 3); Serial.println("A");
  Serial.print("Sensor Offset: "); Serial.println(sensorOffset);
  Serial.print("MPU Status: "); Serial.println(mpu_ok ? "Connected" : "Disconnected");
  Serial.println("------------------------------------");

  if (faultList.length() > 0) {
    if (now - lastFaultGeneration >= FAULT_GENERATION_COOLDOWN) {
      lastFaultGeneration = now;
      String msg = String(NODE_ID) + " -> FAULTS: [" + faultList + "]";
      Serial.println("Generating new fault message: " + msg);
      forwardMsg(msg, NULL);
    } else {
      Serial.println("Fault detected but still in cooldown period...");
    }
  }
}

// ---------------- UTILITIES ----------------
float getSensorOffset() {
  // First, wait 60 seconds for sensor stabilization
  Serial.println("Waiting 60 seconds for sensor stabilization...");
  digitalWrite(LED_PIN, HIGH);  // Turn on LED to indicate stabilization period
  
  unsigned long stabilizationStart = millis();
  while (millis() - stabilizationStart < 11000) {
    // Blink LED every 5 seconds to show progress
    if ((millis() - stabilizationStart) % 5000 < 100) {
      digitalWrite(LED_PIN, LOW);
    } else {
      digitalWrite(LED_PIN, HIGH);
    }
    
    // Print progress every 10 seconds
    if ((millis() - stabilizationStart) % 10000 < 100) {
      int secondsRemaining = (11000 - (millis() - stabilizationStart)) / 1000;
      Serial.print("Stabilizing... ");
      Serial.print(secondsRemaining);
      Serial.println(" seconds remaining");
    }
    
    delay(100);
  }
  
  digitalWrite(LED_PIN, LOW);  // Turn off LED
  Serial.println("Stabilization complete. Now taking 10 readings for calibration...");
  
  // Now take 10 readings and average them
  float readings[10];
  float sum = 0;
  
  digitalWrite(LED_PIN, HIGH);  // Turn on LED to indicate calibration period
  
  for (int i = 0; i < 10; i++) {
    readings[i] = analogRead(ACS_PIN);
    sum += readings[i];
    
    Serial.print("Reading ");
    Serial.print(i + 1);
    Serial.print(": ");
    Serial.println(readings[i]);
    
    // Brief LED blink for each reading
    digitalWrite(LED_PIN, LOW);
    delay(200);
    digitalWrite(LED_PIN, HIGH);
    delay(800);
  }
  
  digitalWrite(LED_PIN, LOW);  // Turn off LED
  
  float average = sum / 10.0;
  Serial.print("Calibration complete. Average of 10 readings: ");
  Serial.println(average);
  
  return average;
}

float getACCurrent() {
  const int samples = 200;
  long sum = 0;
  int sampleCount = 0;
  
  unsigned long startTime = micros();
  
  while (micros() - startTime < 20000 && sampleCount < samples) {
    int val = analogRead(ACS_PIN);
    float centered = val - sensorOffset;
    sum += centered * centered;
    sampleCount++;
    delayMicroseconds(50);
  }
  
  if (sampleCount == 0) return 0;
  
  float rms = sqrt(sum / (float)sampleCount);
  float voltage = rms * (3.3 / 1023.0);
  float sensitivity = 0.185;
  float current = voltage / sensitivity;
  current *= 0.9;
  
  if (current < 0) current = 0;
  
  return current;
}

void recalibrateCurrentSensor() {
  const int quickSamples = 100;
  long sum = 0;
  
  for (int i = 0; i < quickSamples; i++) {
    sum += analogRead(ACS_PIN);
    delay(1);
  }
  
  float newOffset = sum / (float)quickSamples;
  
  if (abs(newOffset - sensorOffset) > 2.0) {
    sensorOffset = newOffset;
    Serial.print("Recalibrated sensor offset: ");
    Serial.println(sensorOffset);
  }
  
  lastRecalibration = millis();
}
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

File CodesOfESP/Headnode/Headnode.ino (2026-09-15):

/* 
  ESP32 HQ - LoRa <-> ESP-NOW bridge + Sensor Suite (BH1750, MPU6050, ACS)
  - For ESP32
  - LoRa receives packets from Laptop-LoRa and forwards them to branch nodes via ESP-NOW
  - ESP-NOW receives messages from branch nodes and forwards them via LoRa to Laptop
  - Includes sensor checks and fault reporting (forwards as ESP-NOW and LoRa)
  - Updated with advanced current sensor and pole fall detection logic
  - Modified to continue booting even if hardware is not detected
  - MODIFIED: Pole fall alerts sent directly via LoRa (not ESP-NOW)
  - MODIFIED: Increased sensitivity for pole fall detection
  - MODIFIED: Improved current sensor calibration with 60s stabilization
*/

#include <Wire.h>
#include <SPI.h>
#include <LoRa.h>
#include <WiFi.h>
#include <esp_now.h>
#include <BH1750.h>
#include <MPU6050.h>
#include <math.h>

// ---------------- CONFIG / IDs ----------------
#define LORA_ID   4        // LoRa network destination ID for Laptop-bridge
#define HQ_ID     4000     // This HQ's ID used as SRC in forwarded messages
#define SERIAL_BAUD 9600

// ---------------- PINS ----------------
const int BUZZER_PIN = 25;    
const int LED_PIN    = 2;
const int LORA_SS    = 5;
const int LORA_RST   = 15;   // *** CHANGED from 14 to 15 to avoid LED conflict ***
const int LORA_DIO0  = 26;
const long LORA_FREQ = 433E6;
const int I2C_SDA = 21;
const int I2C_SCL = 22;
const int ACS_PIN = 33;       // Pin for ACS sensor
const int WIFI_CHANNEL = 1;

// ---------------- ESP-NOW Peers ----------------
uint8_t node1Mac[6] = {0x58,0xBF,0x25,0xDC,0xB9,0xFA};
uint8_t node2Mac[6] = {0x58,0xBF,0x25,0xDC,0xB9,0xFA};
uint8_t *peers[] = { node1Mac, node2Mac };
const int NUM_PEERS = sizeof(peers) / sizeof(peers[0]);

// ---------------- OBJECTS ----------------
BH1750 lightMeter;
MPU6050 mpu;

// ---------------- FLAGS ----------------
bool bh1750_ok = false;
bool mpu_ok   = false;
bool lora_ok  = false;  // Added flag for LoRa status
bool espnow_ok = false; // Added flag for ESP-NOW status

// ---------------- THRESHOLDS ----------------
const float LUX_THRESHOLD        = 300.0;  // Before it was 500
const unsigned long READ_INTERVAL= 1000;
const float TILT_THRESHOLD       = 45.0;
const float CURRENT_THRESHOLD    = 0.055; // It is changing for different ESPs and Different sensor units
const float alpha                = 0.1;
const int SAMPLE_COUNT           = 10;

// Pole fallen detection parameters - INCREASED SENSITIVITY
const float SPEED_CHANGE_THRESHOLD = 0.3;  // DECREASED from 0.8 for higher sensitivity
const float ANGLE_CHANGE_THRESHOLD = 5.0;  // DECREASED from 10.0 for higher sensitivity
const float ABSOLUTE_TILT_THRESHOLD = 40.0; // DECREASED from 55.0 for higher sensitivity
const unsigned long POLE_FALL_COOLDOWN = 30000;
const unsigned long POLE_FALL_CHECK_INTERVAL = 50; // Check every 50ms

// Noise filtering
const float NOISE_THRESHOLD = 0.05; // DECREASED from 0.1 for higher sensitivity
const int STABLE_READINGS = 1; // DECREASED from 2 for faster response

// Current sensor specific variables
unsigned long lastRecalibration = 0;
const unsigned long RECALIBRATION_INTERVAL = 60000;

// Fault generation cooldown
static unsigned long lastFaultGeneration = 0;
const unsigned long FAULT_GENERATION_COOLDOWN = 30000;

// ---------------- GLOBAL VARS ----------------
float sensorOffset     = 0.0;
float filteredCurrent  = 0.0;
bool calibrated        = false;
bool poleFallen        = false;
float baselineX=0.0, baselineY=0.0, baselineZ=1.0;

// For tracking changes in acceleration and angle
float prevAccelX = 0.0, prevAccelY = 0.0, prevAccelZ = 0.0;
float prevAngle = 0.0;
unsigned long lastPoleFallAlert = 0;
unsigned long lastPoleFallCheck = 0;
unsigned long lastMPUCheck = 0;
const unsigned long MPU_RECHECK_INTERVAL = 5000;

// Noise filtering variables
float stableAx = 0.0, stableAy = 0.0, stableAz = 0.0;
int stableCount = 0;

float luxSamples[SAMPLE_COUNT];
bool lightStates[SAMPLE_COUNT];
int sampleIndex = 0;
bool bufferFilled = false;

unsigned long lastCurrentRead = 0;
unsigned long lastSend        = 0;

unsigned long alertStart   = 0;
bool alertActive           = false;
unsigned long alertDurationMs = 0;

// LoRa send cooldown
unsigned long lastLoRaSend = 0;
const unsigned long SEND_COOLDOWN_MS = 100;

// ---------------- FUNCTION DECLARATIONS ----------------
void setupLoRa();
void setupEspNow();
void forwardViaEspNow(const String &payload);
void forwardViaLoRa(const String &payload);
void onLoRaReceive(int packetSize);
void triggerBuzzerFor(unsigned long ms);
void beep(int t);
float getSensorOffset();
float getACCurrent();
void calibrateMPU();
void checkSensors();
void recalibrateCurrentSensor();
void checkPoleFallAsync();
bool initializeMPU();
void sendPoleFallFault();

// ✅ Updated ESP-NOW callback declarations (for ESP-IDF v5.x)
void onEspNowRecv(const esp_now_recv_info *info, const uint8_t *incomingData, int len);
void onEspNowSent(const wifi_tx_info_t *info, esp_now_send_status_t status);

// ---------------- SETUP ----------------
void setup() {
  Serial.begin(SERIAL_BAUD);
  delay(200);
  Serial.println("===== ESP32 HQ BOOT =====");
  Serial.printf("LoRa ID = %d | HQ ID = %d\n", LORA_ID, HQ_ID);

  pinMode(BUZZER_PIN, OUTPUT);
  // pinMode(LED_PIN, OUTPUT);
  digitalWrite(BUZZER_PIN, LOW);
  digitalWrite(LED_PIN, LOW);
  
  Wire.begin(I2C_SDA, I2C_SCL);

  // Initialize MPU6050 first
  mpu_ok = initializeMPU();
  
  bh1750_ok = lightMeter.begin();
  if (bh1750_ok) Serial.println("BH1750 OK");
  else Serial.println("BH1750 not detected");

  // Calibrate current sensor - wait 60s for stabilization, then average 10 readings
  Serial.println("Calibrating current sensor... This will take approximately 70 seconds.");
  sensorOffset = getSensorOffset();
  Serial.print("Initial Sensor Offset: "); Serial.println(sensorOffset);
  lastRecalibration = millis();
  
  if (mpu_ok) calibrateMPU();

  setupLoRa();
  setupEspNow();

  // Print system status
  Serial.println("\n===== SYSTEM STATUS =====");
  Serial.printf("LoRa: %s\n", lora_ok ? "OK" : "FAILED");
  Serial.printf("ESP-NOW: %s\n", espnow_ok ? "OK" : "FAILED");
  Serial.printf("BH1750: %s\n", bh1750_ok ? "OK" : "FAILED");
  Serial.printf("MPU6050: %s\n", mpu_ok ? "OK" : "FAILED");
  Serial.println("========================\n");

  Serial.println("System ready.\n");
}
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
